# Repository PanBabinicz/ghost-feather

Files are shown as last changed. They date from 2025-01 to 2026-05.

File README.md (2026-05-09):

# Ghost Feather



> [!NOTE]
> **Please bear in mind that the workspace was primarily created for enjoyment
> and educational endeavors.**

> The MIT License (MIT)
>
> Copyright (c) 2011-2024 The Bootstrap Authors
>
> Permission is hereby granted, free of charge, to any person obtaining a copy
> of this software and associated documentation files (the "Software"), to deal
> in the Software without restriction, including without limitation the rights
> to use, copy, modify, merge, publish, distribute, sublicense, and/or sell
> copies of the Software, and to permit persons to whom the Software is
> furnished to do so, subject to the following conditions:
>
> The above copyright notice and this permission notice shall be included in
> all copies or substantial portions of the Software.
>
> THE SOFTWARE IS PROVIDED "AS IS", WITHOUT WARRANTY OF ANY KIND, EXPRESS OR
> IMPLIED, INCLUDING BUT NOT LIMITED TO THE WARRANTIES OF MERCHANTABILITY,
> FITNESS FOR A PARTICULAR PURPOSE AND NONINFRINGEMENT. IN NO EVENT SHALL THE
> AUTHORS OR COPYRIGHT HOLDERS BE LIABLE FOR ANY CLAIM, DAMAGES OR OTHER
> LIABILITY, WHETHER IN AN ACTION OF CONTRACT, TORT OR OTHERWISE, ARISING FROM,
> OUT OF OR IN CONNECTION WITH THE SOFTWARE OR THE USE OR OTHER DEALINGS IN
> THE SOFTWARE.

# Compilation process

> [!NOTE]
> **The current compilation process will be changed**

```console
~ arm-none-eabi-gcc -g -c -mfloat-abi=hard -mfpu=fpv4-sp-d16 -mcpu=cortex-m7 -mthumb \
                          -I memory -I bootloader \
                          startup/stm32f722xx/stm32722xx_startup.c -o build/stm32f722xx_startup.o
```

```console
~ arm-none-eabi-gcc -g -c -mfloat-abi=hard -mfpu=fpv4-sp-d16 -mcpu=cortex-m7 -mthumb \
                          -I libopencm3/include -I memory -DSTM32F7 \
                          bootloader/stm32f722xx_first_bootloader.c -o build/stm32f722xx_first_bootloader.o
```

```console
~ arm-none-eabi-as -g vectortable/stm32f722xx/stm32f722xx_vectortable.S -o build/stm32f722xx_vectortable.o
```

```console
~ arm-none-eabi-gcc -g -nostartfiles -nostdlib -mfloat-abi=hard -mfpu=fpv4-sp-d16 -mcpu=cortex-m7 -mthumb \
                       build/stm32f722xx_first_bootloader.o build/stm32f722xx_startup.o build/stm32f722xx_vectortable.o -o build/stm32f722xx_first_bootloader.elf \
                       -T linkerscript/stm32f722xx/stm32f722xx_bootloader.ld -L linkerscript/stm32f722xx -L libopencm3/lib -lopencm3_stm32f7
```

## CMake generators

> **Unix Makefiles**
>
> ```console
> ~ cmake -S . -B build -DCMAKE_TOOLCHAIN_FILE=arm-none-eabi-toolchain.cmake
> ~ cd build
> ~ cmake --build . --config Debug
> ```

> **Ninja Multi-Config**
>
> ```console
> ~ cmake -G "Ninja Multi-Config" -S . -B build -DCMAKE_TOOLCHAIN_FILE=arm-none-eabi-toolchain.cmake
> ~ cd build
> ~ cmake --build . --config Debug
> ```

> **CMake Presets**
>
> ```console
> ~ cmake --preset list
> ~ cmake --preset <build-type>
> ```

> **Build shell script**
>
> ```console
> ~ ./build.sh <build-type>
> ```

# How to program

> For now, CMake generates two elf files. Each of these files needs to be uploaded to the device.

# Newlib

> To use newlib with libopencm3 it is necessary to recomplie the libc to be able to use hard floating point numbers which use on-chip FPU.
> The second option is to use soft floating point numbers but the speed will be slower.

# Marco Paland printf implementation

> The Marco Paland printf implementation is a lightweight, standalone alternative designed
> specifically to address these limitations. This implementation offers a small memory footprint,
> portability, and independence from the full C standard library. It is widely used in embedded
> projects where developers require formatted output but cannot afford the code size and
> dependencies of a complete libc implementation.

# DFU script

> **Description**
>
> The script enables firmware update over USART. It allows users to upload binary firmware files to microcontroller-based devices with minimal effort.
> The script handles communication setup, data formatting, and transmission to ensure reliable updates.

> **Usage**
>
> ```console
> ~ python3 dfu_usart.py <binary> <port> <baudrate>
> ```
>
> - `<binary>`:   The firmware to be uploaded.
> - `<port>`:     The name of the serial port connected to the target device (e.g., /dev/tty.usbmodem).
> - `<baudrate>`: The communication speed in bits per second (e.g., 9600, 115200).

# SOCAT tool

> **Usage**
>
> ```console
> ~ socat -d -d PTY,raw,echo=0 PTY,raw,echo=0
> ~ stty -f /dev/ttysxxx 115200
> ~ screen /dev/ttysxxx 115200
> ```

# Unit tests

> **Description**
>
> The unit tests verify the functionality, reliability, and error handling of embedded system controllers using Google Test (GTest).
>
> They cover various scenarios, including:
> - Core functionality validation.
> - Boundary condition testing.
> - Error handling and fault tolerance.
> - Performance and efficiency checks.

> **Usage**
>
> ```console
> ~ cmake -G "Ninja" -S . -B build -DPROJECT_ROOT_DIR=$(pwd)/../..
> ~ cmake --build build
> ~ cd build && ctest
> ```

# Conda

## What is Conda?

> Conda is an open-source **package manager and environment manager** used for installing, running, and
> updating software packages and their dependencies. It is widely used in data science, machine learning,
> and scientific computing because it simplifies managing complex software environments.
>
> Unlike `pip`, which only installs Python packages, **Conda can manage packages written in multiple languages**
> (such as Python, R, and C libraries) and handles system-level dependencies as well.
>
> Conda is distributed with platforms such as:

- **Anaconda** – a large distribution that includes many preinstalled scientific packages.
- **Miniconda** – a lightweight version that installs only Conda and Python.

## Why Use Conda?

> Conda helps solve common development problems:

- **Dependency management** – automatically installs required libraries.
- **Environment isolation** – different projects can use different package versions.
- **Cross-language support** – works with Python, R, and other tools.
- **Reproducibility** – environments can be exported and recreated.

> Example: one project may require `Python 3.9` while another requires `Python 3.11`. Conda allows both to
> coexist without conflicts.

## Creating an Environment

> A Conda environment is an isolated workspace containing its own Python version and installed packages.
>
> Create a new environment:

```bash
conda create -n myenv python=3.10
```

Here:
- `-n myenv` specifies the environment name
- `python=3.10` installs a specific Python version

## Activating an Environment

> Before using an environment, it must be activated.

```bash
conda activate myenv
```

> After activation, all installed packages and Python commands will come from this environment.
>
> To deactivate:

```bash
conda deactivate
```

## Installing Packages

> Packages can be installed directly into the active environment.

```bash
conda install numpy pandas matplotlib
```

> Conda will automatically resolve and install required dependencies.

## Listing Environments

> To see all available environments:

```bash
conda env list
```

> or:

```bash
conda info --envs
```

## Removing an Environment

> If an environment is no longer needed, it can be deleted:

```bash
conda remove -n myenv --all
```

## Exporting an Environment

> To share or reproduce an environment:

```bash
conda env export > environment.yml
```

> This file can later be used to recreate the same environment.

## Recreating an Environment

```bash
conda env create -f environment.yml
```

> This installs all packages and dependencies exactly as defined in the exported file.

## EASTER EGG!

> CBR 929 broke. We have to repair it. I will do todays job tomorrow.

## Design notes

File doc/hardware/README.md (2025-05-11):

# Hardware

## Important links

> Phil's lab
>
> Bluetooth Hardware Design  
> https://www.youtube.com/watch?v=nkHFoxe0mrU&ab_channel=Phil%E2%80%99sLab  
> https://www.youtube.com/watch?v=PlXd3lLZ4vc&t=16s&ab_channel=Phil%E2%80%99sLab

> Over-the-Air DFU procedure
>
> https://onlinedocs.microchip.com/oxy/GUID-26457D23-798C-47B0-9F40-C5DA6E995C6F-en-US-2/GUID-79B3231C-7BD0-4459-80A5-A198A4F1B366.html

## 🖥 PCB Design Software

> KiCad
>
> KiCad is a free and open-source software suite for designing schematics and PCB layouts.
> It is widely used in the electronics community for both hobbyist and professional projects.

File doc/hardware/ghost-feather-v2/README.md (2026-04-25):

# 👻 Ghost Feather v2

## Introduction

> [!NOTE]  
> **Please bear in mind that the pcb was primarily created for enjoyment  
> and educational endeavors.**

> Ghost Feather v2 is a compact, four-layer PCB built for embedded systems and robotics exploration 🤖.
> This revision evolves the original design into a more capable flight-control-oriented platform,
> integrating additional sensors and support for modern FPV and radio systems.
>
> ✨ This version expands beyond basic functionality, introducing orientation awareness, altitude sensing,
> and improved control reliability.

## ✨ Key Features

- 🧠 STM32F722RET6 – Powerful Cortex-M7 MCU at the heart of the board

- 🌀 BMI088 IMU – High-performance 6-axis sensor optimized for vibration-heavy environments

- 🧭 IIS2MDCTR Magnetometer – 3-axis magnetic field sensing for heading and navigation

- 🌡️ BMP390 Barometer – High-resolution pressure sensor for altitude estimation

- 📡 External ELRS Receiver Support – Designed for use with Radiomaster RP3 (ExpressLRS 2.4 GHz) via CRSF protocol

- 🧪 Voltage Level Shifters – Built using MOSFETs to safely bridge logic levels

- 🛠️ SWD Tag Connector – For easy debugging and programming

- 🔌 4x PicoBlade Connectors – For connecting ESCs (Electronic Speed Controllers)

- 📡 1x PicoBlade Connector – Reserved for RF receiver (UART: CRSF)

- 🎥 FPV Camera Support – Dedicated power and video signal connections for analog FPV systems

## 🔧 Design Notes

- The board is designed to work with external ExpressLRS receivers, such as the Radiomaster RP3, avoiding the
  complexity of onboard RF design.

- Sensor suite upgrades (IMU, magnetometer, barometer) allow for advanced flight control and navigation
  capabilities.

- FPV support is implemented at the hardware level (power + signal routing), without onboard video processing.

## 🚧 Future Improvements

- Blackbox logging (SPI flash)
- OSD support (e.g., AT7456E)
- USB-C interface
- Improved power filtering for analog systems

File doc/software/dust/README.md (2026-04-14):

# DUST protocol

## Description

> The DUST communication protocol is a lightweight and reliable data transfer mechanism designed for
> Device Firmware Update (DFU) operations in ghost feather system. It supports flexible payload sizes, allowing
> efficient transmission of firmware data across varying link conditions. Data integrity is ensured through
> integrated CRC and checksum validation, minimizing the risk of corrupted updates. The protocol includes
> acknowledgment and retransmission mechanisms to guarantee delivery and robustness in unstable or lossy communication
> environments.

## Protocol structures

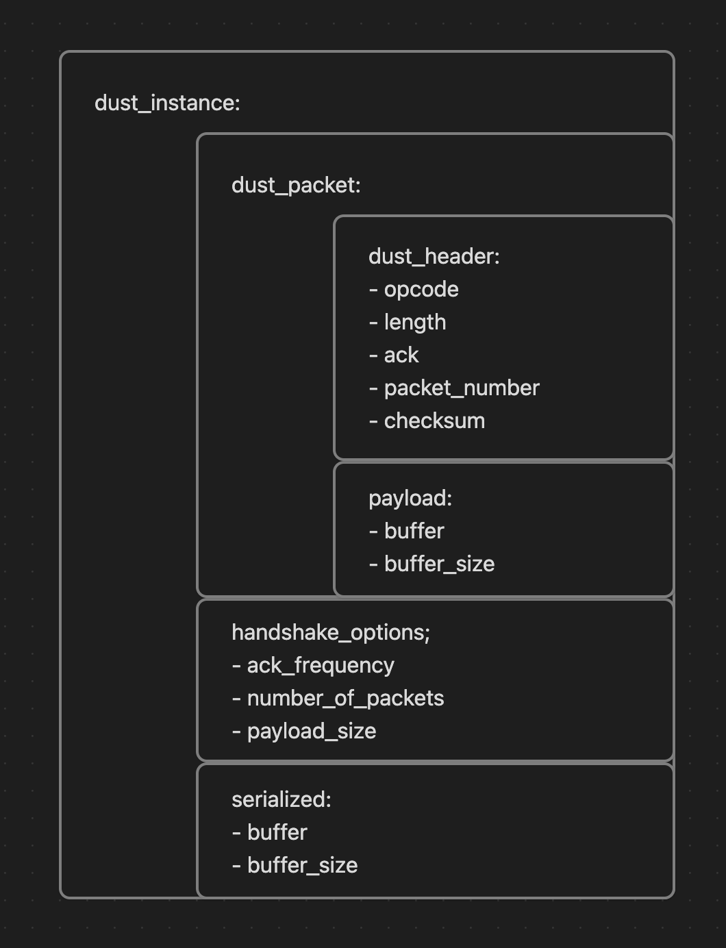
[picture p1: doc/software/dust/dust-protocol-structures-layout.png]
dust-protocol-structures-layout


## Packet structure

> <table class="tg"><thead>
>   <tr>
>     <td class="tg-uzvj" rowspan="12">DUST<br>PACKET</td>
>     <td class="tg-uzvj" rowspan="5">HEADER<br>(4bytes)</td>
>     <td class="tg-7btt">OPCODE<br>(2bits)</td>
>   </tr>
>   <tr>
>     <td class="tg-7btt">LENGTH<br>(2bits)</td>
>   </tr>
>   <tr>
>     <td class="tg-7btt">ACK FLAG<br>(1bit)</td>
>   </tr>
>   <tr>
>     <td class="tg-7btt">PACKET NUMBER<br>(11bits)</td>
>   </tr>
>   <tr>
>     <td class="tg-7btt">CHECKSUM<br>(16bits)</td>
>   </tr>
>   <tr>
>     <td class="tg-uzvj" rowspan="6">PAYLOAD<br>(32-256bytes)</td>
>     <td class="tg-uzvj">DATA[0]</td>
>   </tr>
>   <tr>
>     <td class="tg-uzvj">DATA[1]</td>
>   </tr>
>   <tr>
>     <td class="tg-uzvj">DATA[3]</td>
>   </tr>
>   <tr>
>     <td class="tg-uzvj">...</td>
>   </tr>
>   <tr>
>     <td class="tg-uzvj">DATA[n-1]</td>
>   </tr>
>   <tr>
>     <td class="tg-uzvj">DATA[n]</td>
>   </tr>
>   <tr>
>     <td class="tg-uzvj">CRC16<br>(2bytes)</td>
>     <td class="tg-uzvj">CRC16<br></td>
>   </tr></thead></table>

### OPCODE (2 bits wide)

> | OPCODE     | VALUE |
> |------------|-------|
> | CONNECT    | 0x00  |
> | DISCONNECT | 0x01  |
> | DATA       | 0x02  |
> | ERROR      | 0x03  |
>
> ### LENGTH (2 bits wide)
>
> | LENGTH     | VALUE |
> |------------|-------|
> | BYTE32     | 0x00  |
> | BYTE64     | 0x01  |
> | BYTE128    | 0x02  |
> | BYTE256    | 0x03  |
>
> ### ACK (1 bits wide)
>
> | LENGTH     | VALUE |
> |------------|-------|
> | UNSET      | 0x00  |
> | SET        | 0x01  |

### PACKET NUMBER (11 bits wide)

> The packet number is used to enumerate the packets. When error occurs the transmitter is signaled which
> packet was corrupted with the help of this filed.

### CHECKSUM (16 bits wide)

> The checksum purpose is error detection that may have been introduced during header transmission.
>
> Algorithm used to calculate the checksum:
>
> ``` code
> checksum = ((opcode << 0x0e) | (length << 0x0c) | (ack << 0x0b) | (packet_number << 0x00));
> checksum = ~checksum;
> ```

### HANDSHAKE OPTIONS

> Handshake options are send in payload when a connection attempt is made.
> The first byte stores information about ACK packet frequency (rate), the next four bytes have information about number of packets.

## Connection establishment (handshake)

> The connection establishment sets the payload size for future data packets. In this process only header is sent.
> The receiver calculates the checksum of the header and check it's correctness. It then sends an ACK header.

```mermaid
sequenceDiagram
    UPDATER->>DEVICE: CONNECT PACKET
    DEVICE-->>UPDATER: CONNECT ACK PACKET
```

### CONNECT PACKET

> <table class="tg"><thead>
>   <tr>
>     <td class="tg-uzvj" rowspan="12">DUST<br>PACKET</td>
>     <td class="tg-uzvj" rowspan="5">HEADER<br>(4bytes)</td>
>     <td class="tg-7btt">0x00<br>(2bits)</td>
>   </tr>
>   <tr>
>     <td class="tg-7btt">0x00<br>(2bits)</td>
>   </tr>
>   <tr>
>     <td class="tg-7btt">0x00<br>(1bit)</td>
>   </tr>
>   <tr>
>     <td class="tg-7btt">0x00<br>(11bits)</td>
>   </tr>
>   <tr>
>     <td class="tg-7btt">0xffff<br>(16bits)</td>
>   </tr>
>   <tr>
>     <td class="tg-uzvj" rowspan="6">PAYLOAD<br>(32-256bytes)</td>
>     <td class="tg-uzvj">0x00</td>
>   </tr>
>   <tr>
>     <td class="tg-uzvj">0x00</td>
>   </tr>
>   <tr>
>     <td class="tg-uzvj">0x00</td>
>   </tr>
>   <tr>
>     <td class="tg-uzvj">...</td>
>   </tr>
>   <tr>
>     <td class="tg-uzvj">0x00</td>
>   </tr>
>   <tr>
>     <td class="tg-uzvj">0x00</td>
>   </tr>
>   <tr>
>     <td class="tg-uzvj">CRC16<br>(2bytes)</td>
>     <td class="tg-uzvj">0xa9b8<br></td>
>   </tr></thead>
> </table>

### CONNECT ACK PACKET

> <table class="tg"><thead>
>   <tr>
>     <td class="tg-uzvj" rowspan="12">DUST<br>PACKET</td>
>     <td class="tg-uzvj" rowspan="5">HEADER<br>(4bytes)</td>
>     <td class="tg-7btt">0x00<br>(2bits)</td>
>   </tr>
>   <tr>
>     <td class="tg-7btt">0x00<br>(2bits)</td>
>   </tr>
>   <tr>
>     <td class="tg-7btt">0x01<br>(1bit)</td>
>   </tr>
>   <tr>
>     <td class="tg-7btt">0x00<br>(11bits)</td>
>   </tr>
>   <tr>
>     <td class="tg-7btt">0xffff<br>(16bits)</td>
>   </tr>
>   <tr>
>     <td class="tg-uzvj" rowspan="6">PAYLOAD<br>(32-256bytes)</td>
>     <td class="tg-uzvj">0x00</td>
>   </tr>
>   <tr>
>     <td class="tg-uzvj">0x00</td>
>   </tr>
>   <tr>
>     <td class="tg-uzvj">0x00</td>
>   </tr>
>   <tr>
>     <td class="tg-uzvj">...</td>
>   </tr>
>   <tr>
>     <td class="tg-uzvj">0x00</td>
>   </tr>
>   <tr>
>     <td class="tg-uzvj">0x00</td>
>   </tr>
>   <tr>
>     <td class="tg-uzvj">CRC16<br>(2bytes)</td>
>     <td class="tg-uzvj">0x3508<br></td>
>   </tr></thead>
> </table>

## Data transmission

> During data transmission, firmware bytes are sent in the payload.
> The rate of ACK packets depends on the options passed during the handshake.

 ```mermaid
 sequenceDiagram
     UPDATER->>DEVICE: DATA[0] PACKET
     UPDATER->>DEVICE: DATA[1] PACKET
     UPDATER->>DEVICE: DATA[2] PACKET
     UPDATER->>DEVICE: ...
     UPDATER->>DEVICE: DATA[n] PACKET
     DEVICE-->>UPDATER: DATA ACK PACKET
     UPDATER->>DEVICE: DATA[n+1] PACKET
     UPDATER->>DEVICE: ...
 ```

## Disconnection

> Disconnection is performed from slave side. The device that updates itself
> sends the disconnection packet after the last data is received.

 ```mermaid
 sequenceDiagram
     DEVICE-->>UPDATER: DISCONNECTION PACKET
     UPDATER->>DEVICE: DISCONNECTION PACKET ACK
 ```

### DISCONNECTION PACKET

> <table class="tg"><thead>
>   <tr>
>     <td class="tg-uzvj" rowspan="12">DUST<br>PACKET</td>
>     <td class="tg-uzvj" rowspan="5">HEADER<br>(4bytes)</td>
>     <td class="tg-c3ow">0x01</td>
>   </tr>
>   <tr>
>     <td class="tg-c3ow">0x00</td>
>   </tr>
>   <tr>
>     <td class="tg-c3ow">0x00</td>
>   </tr>
>   <tr>
>     <td class="tg-9wq8">0x00</td>
>   </tr>
>   <tr>
>     <td class="tg-c3ow">0xbfff</td>
>   </tr>
>   <tr>
>     <td class="tg-uzvj" rowspan="6">PAYLOAD<br>(32-256bytes)</td>
>     <td class="tg-9wq8">0x00</td>
>   </tr>
>   <tr>
>     <td class="tg-9wq8">0x00</td>
>   </tr>
>   <tr>
>     <td class="tg-9wq8"><span style="font-style:normal">0x00</span></td>
>   </tr>
>   <tr>
>     <td class="tg-9wq8">...</td>
>   </tr>
>   <tr>
>     <td class="tg-9wq8"><span style="font-style:normal">0x00</span></td>
>   </tr>
>   <tr>
>     <td class="tg-9wq8"><span style="font-style:normal">0x00</span></td>
>   </tr>
>   <tr>
>     <td class="tg-uzvj">CRC16<br>(2bytes)</td>
>     <td class="tg-9wq8">0x0577</td>
>   </tr></thead>
> </table>

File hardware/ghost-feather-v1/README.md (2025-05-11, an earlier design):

# Ghost Feather - hardware

## PCB used materials

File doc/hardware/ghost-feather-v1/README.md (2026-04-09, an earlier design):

# 👻 Ghost Feather v1

## Introduction

> [!NOTE]
> **Please bear in mind that the pcb was primarily created for enjoyment
> and educational endeavors.**

> Ghost Feather v1 is a compact, four-layer PCB built for embedded systems and robotics exploration 🤖.
> Designed with versatility and performance in mind, it brings together a robust set of components for
> a wide range of applications.
>
> This is the first version of the board, featuring only basic functionality – telemetry and advanced
> features are not yet included.

> ✨ Key Features
>
> - 🧠 STM32F722RET6 – Powerful Cortex-M7 MCU at the heart of the board
>
> - 🌀 BMI270 IMU – 6-axis motion sensing for orientation and motion tracking
>
> - 🧪 Voltage Level Shifters – Built using MOSFETs to safely bridge logic levels
>
> - 🛠️ SWD Tag Connector – For easy debugging and programming
>
> - 🔌 4x PicoBlade Connectors – For connecting ESCs (Electronic Speed Controllers)
>
> - 📡 1x PicoBlade Connector – For connecting an RF radio module

## 📃 Schematic

> This section includes the complete schematic of the board, created with KiCad.
> It outlines the core circuitry, microcontroller wiring, level shifters, connectors, and power.

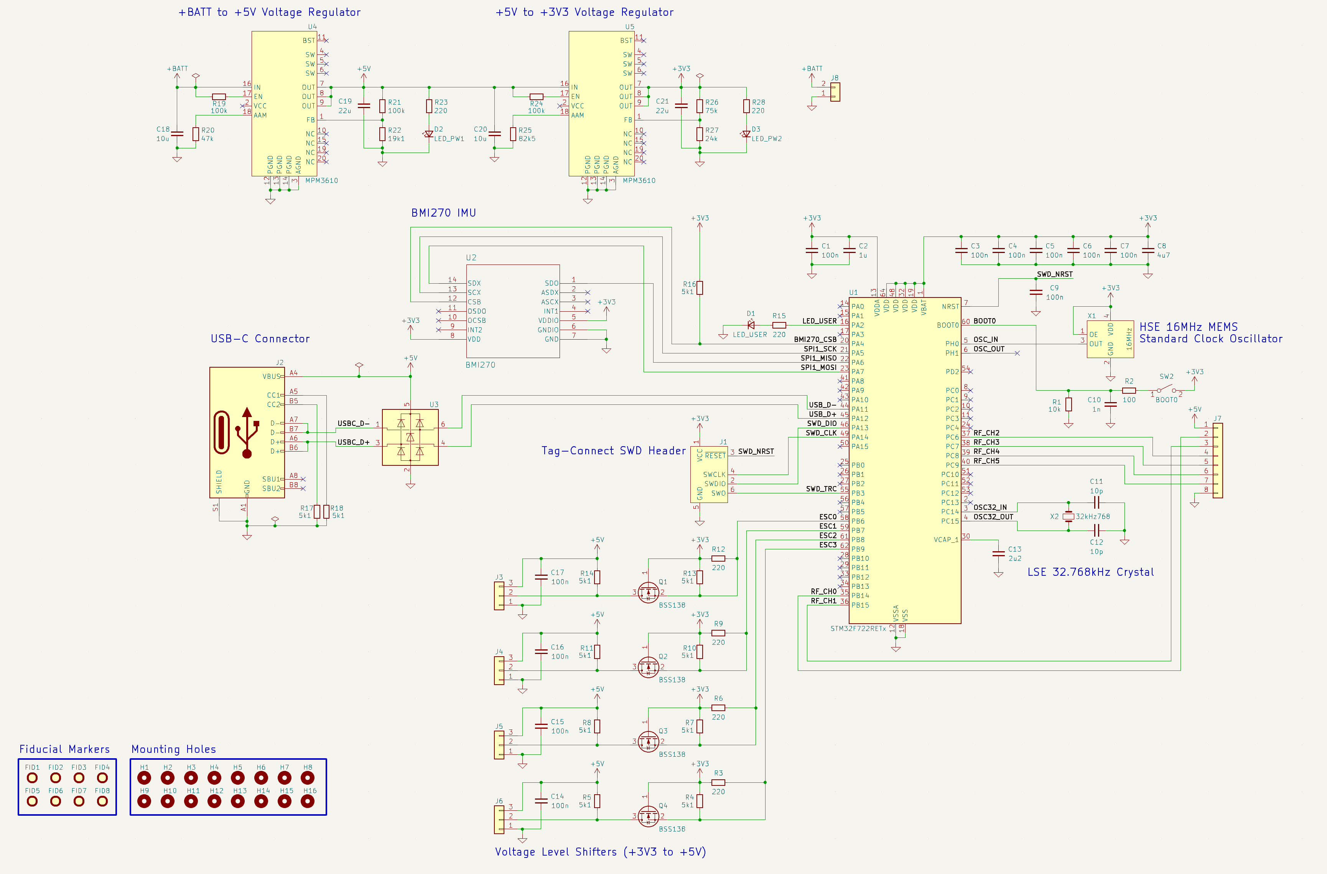
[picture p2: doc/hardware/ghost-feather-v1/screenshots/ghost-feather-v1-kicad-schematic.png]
Schematic


## 🛠️ PCB

> This section showcases the 3D views of the PCB, generated using KiCad.
> These models provide a clear visual reference for component placement,
> board layout, and connector orientation.

### KiCAD 3D Model
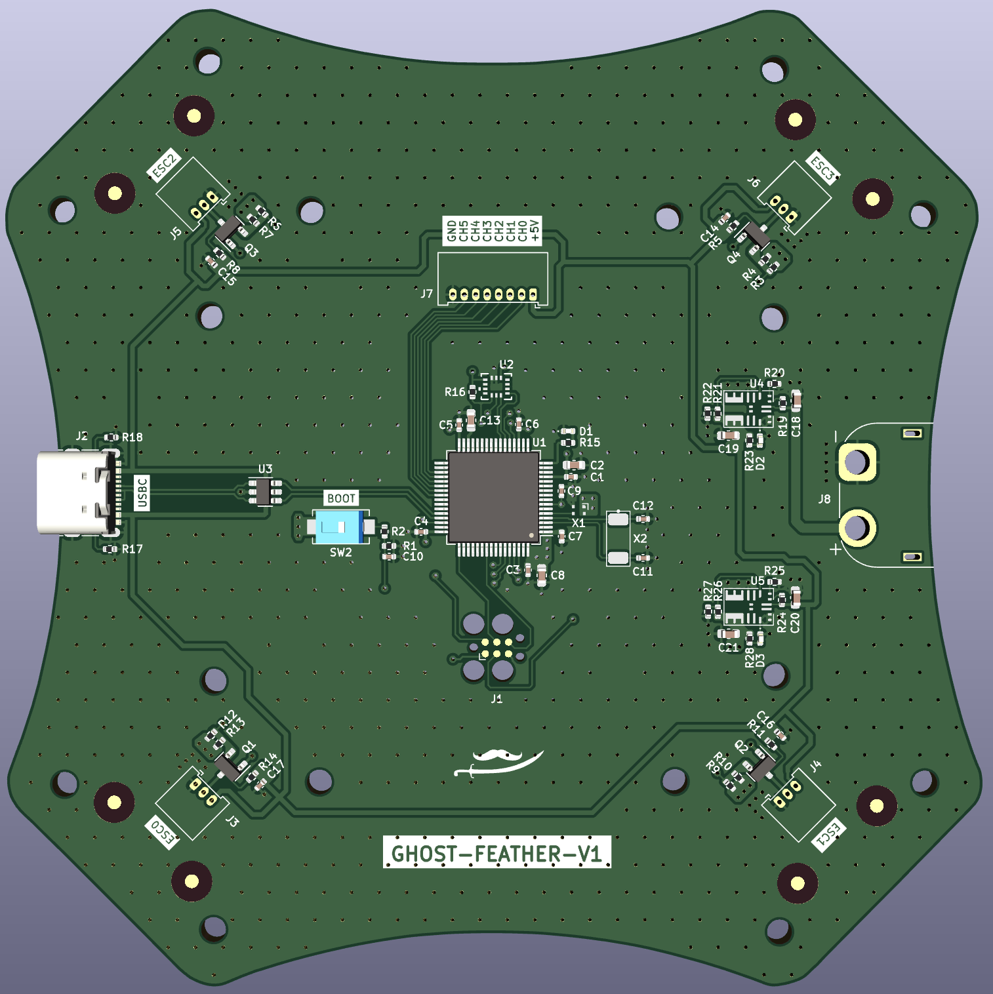
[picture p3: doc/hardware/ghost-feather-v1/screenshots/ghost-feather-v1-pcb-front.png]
Front

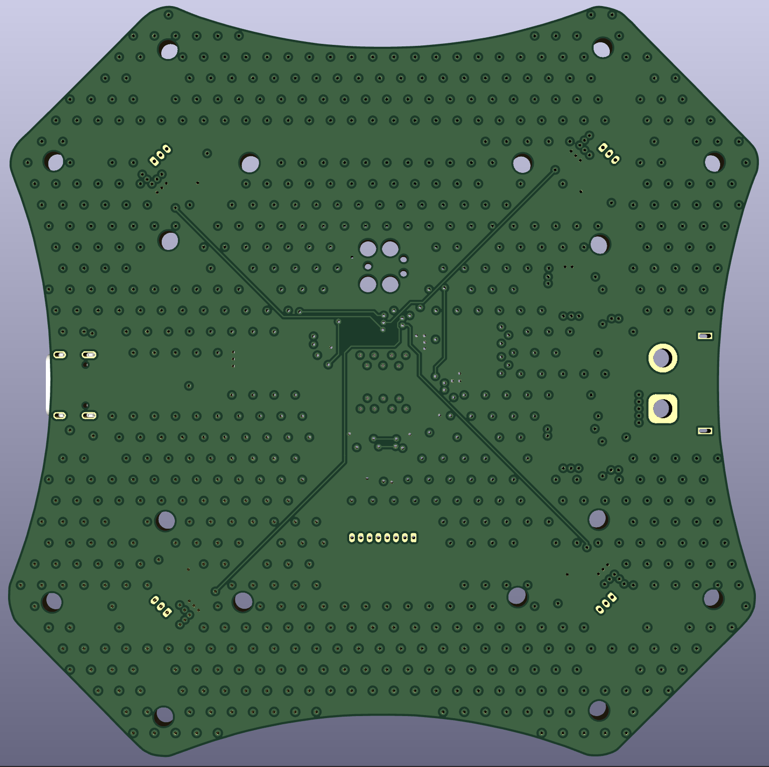
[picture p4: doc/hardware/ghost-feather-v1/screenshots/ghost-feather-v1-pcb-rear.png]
Rear


### Manufactured PCB
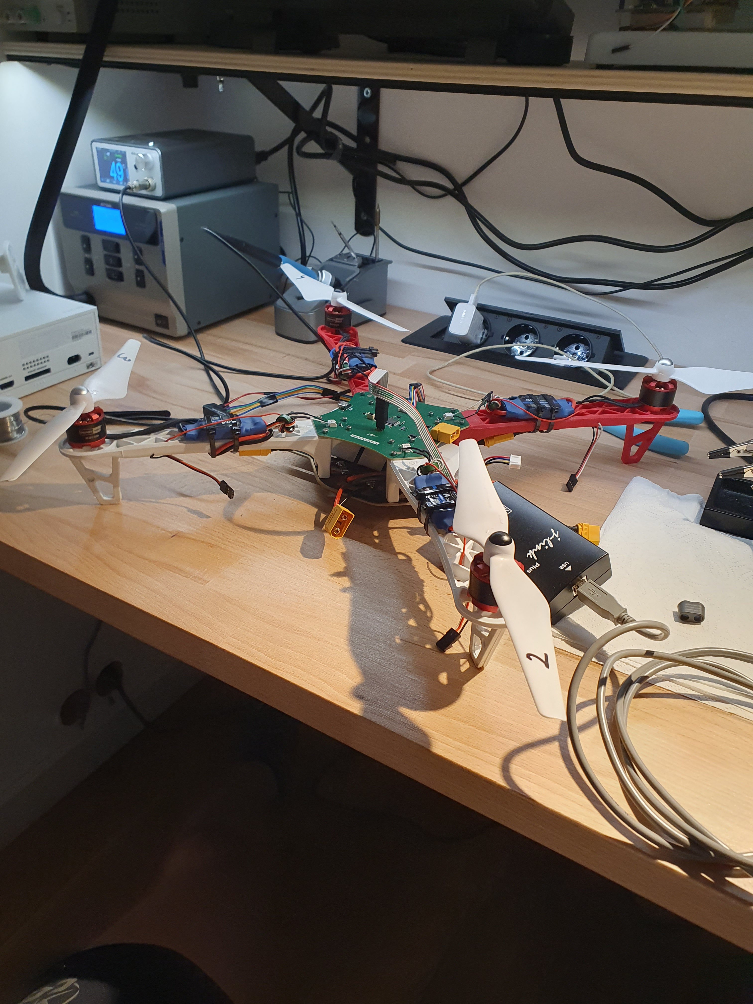
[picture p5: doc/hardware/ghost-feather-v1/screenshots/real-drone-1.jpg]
Bench

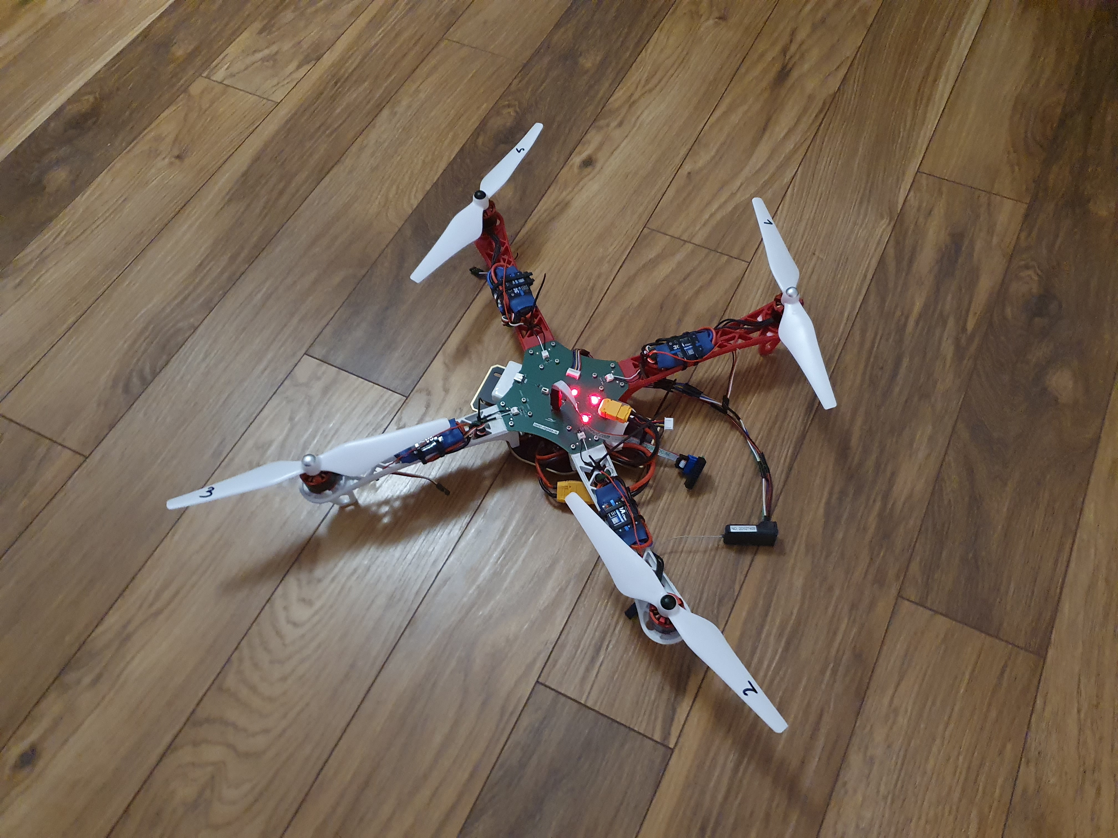
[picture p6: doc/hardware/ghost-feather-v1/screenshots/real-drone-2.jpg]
Floor


## PID Gain Tuning Using a Dedicated Test Stand

### Preparation for tuning PID gains
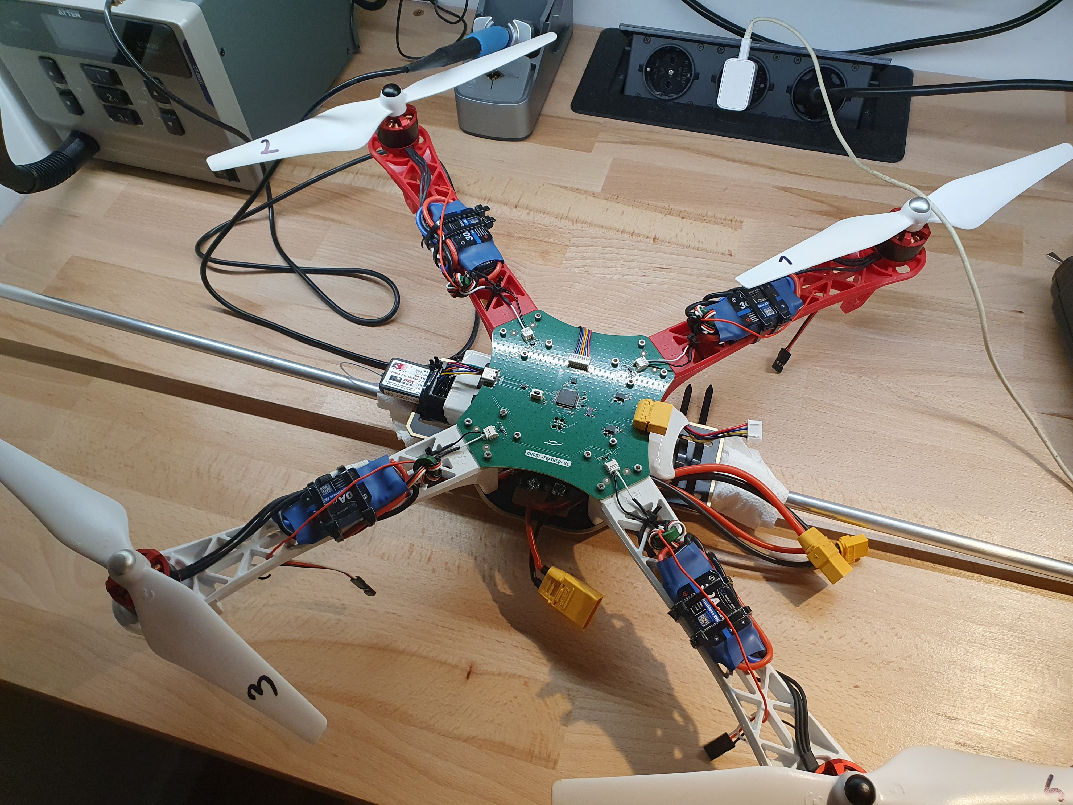
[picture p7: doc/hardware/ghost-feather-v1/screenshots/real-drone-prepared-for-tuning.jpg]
OnBench


> To obtain accurate and repeatable PID gains for the drone, a **dedicated tuning stand** is used. This setup allows controlled
> testing of the control system without the risks and external disturbances associated with free flight.

### 🧩 Purpose

> The tuning stand isolates the drone’s rotational axes (typically roll and pitch) while:
> * preventing full movement or lift-off
> * allowing safe application of control inputs
>
> This creates a controlled environment for systematic PID tuning.

### ⚙️ Setup

> The drone is mounted on a mechanical frame that:
> * constrains motion to one axis at a time
> * minimizes friction and external disturbances
> * allows sensors (e.g., IMU) to operate normally
>
> Only the axis under test (e.g., roll) is left free to rotate, while others are fixed.

### 🔄 Tuning Procedure

#### 1. Proportional Gain (Kp)
> * Start with `Ki = 0`, `Kd = 0`
> * Gradually increase `Kp` until the system responds quickly to disturbances
> * Identify the point where oscillations begin, then slightly reduce `Kp`

#### 2. Derivative Gain (Kd)
> * Increase `Kd` to dampen oscillations
> * Adjust until the system stabilizes quickly without overshoot

#### 3. Integral Gain (Ki)
> * Introduce `Ki` to eliminate steady-state error
> * Increase slowly to avoid drift or slow oscillations

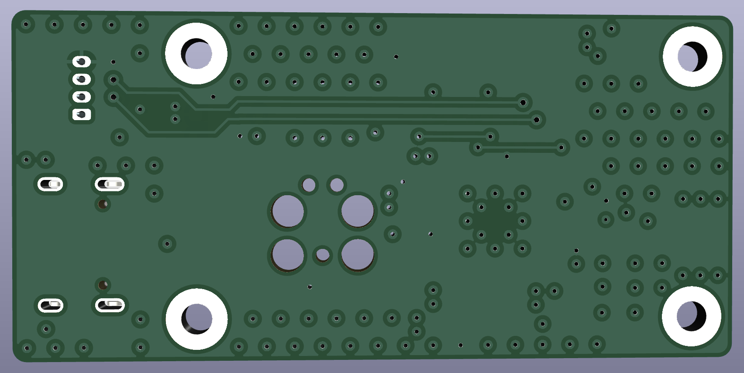
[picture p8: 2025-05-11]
hardware/flying-byte-v1/screenshots/rear.png

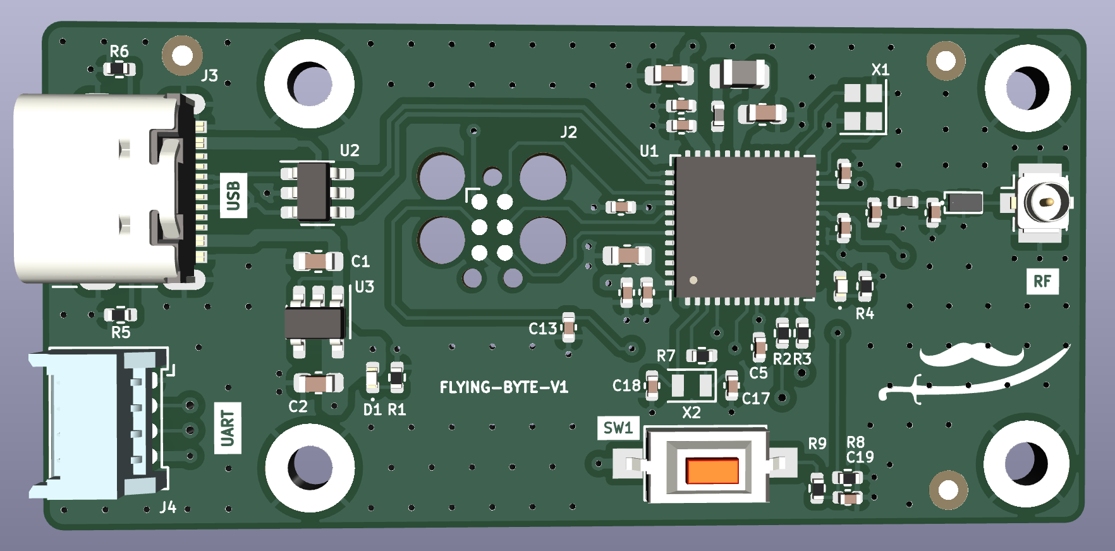
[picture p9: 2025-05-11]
hardware/flying-byte-v1/screenshots/front.png

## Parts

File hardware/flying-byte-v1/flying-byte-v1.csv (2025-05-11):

Reference | Value | Footprint | Datasheet | Distribution Link | Manufacturer Part Number | Manufaturer | Qty
C1-C3, C10, C14 | 4u7 | Capacitor_SMD:C_0603_1608Metric | ~ | https://eu.mouser.com/ProductDetail/Murata-Electronics/GRT188R61E475KE13D | GRT188R61E475KE13D | Murata Electronics | 5
C4-C9, C11-C13, C19 | 100n | Capacitor_SMD:C_0402_1005Metric | ~ | https://eu.mouser.com/ProductDetail/Wurth-Elektronik/885012205092 | 885012205092 | Wurth Elektronik | 10
C15 | 0p8 | Capacitor_SMD:C_0402_1005Metric | ~ | https://eu.mouser.com/ProductDetail/Murata-Electronics/GRM1555C1HR80BA01D?qs=e%252BE4OD6MgMezPYPintwvrA%3D%3D | GRM1555C1HR80BA01D | Murata Electronics | 1
C16 | 0p3 | Capacitor_SMD:C_0402_1005Metric | ~ | https://eu.mouser.com/ProductDetail/Murata-Electronics/GRM1555C1HR30WA01D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 | GRM1555C1HR30WA01D | Murata Electronics | 1
C17, C18 | 10p | Capacitor_SMD:C_0402_1005Metric | ~ | https://eu.mouser.com/ProductDetail/KEMET/C0402C100J5RAC?qs=9vOqFld9vZUpzu%252Bf5E%252Bmyw%3D%3D | C0402C100J5RAC | KEMET | 2
D1, D2 | LED | LED_SMD:LED_0402_1005Metric | ~ | -- mixed values -- | -- mixed values -- | Stanley Electric | 2
FLT1 | DLF162500LT-5028A1 | flying-byte-v1-pcb-footprints:DLF162500LT-5028A1 | https://product.tdk.com/system/files/dam/doc/product/rf/rf/filter/catalog/rf_lpf_dlf162500lt-5028a1_en.pdf | https://eu.mouser.com/ProductDetail/TDK/DLF162500LT-5028A1?qs=U%2FZX79kHR%2FlwIbAISCs3qA%3D%3D | DLF162500LT-5028A1 | TDK | 1
J1 | Conn_Coaxial | Connector_Coaxial:U.FL_Hirose_U.FL-R-SMT-1_Vertical | ~ | https://eu.mouser.com/ProductDetail/Hirose-Connector/U.FL-R-SMT01?qs=Ux3WWAnHpjDV3tCCbDi65g%3D%3D | U.FL-R-SMT(01) | Hirose Connector | 1
J2 | Conn_ARM_SWD_TagConnect_TC2030 | Connector:Tag-Connect_TC2030-IDC-FP_2x03_P1.27mm_Vertical | https://www.tag-connect.com/wp-content/uploads/bsk-pdf-manager/TC2030-CTX_1.pdf |  |  |  | 1
J3 | USB_C_Receptacle_USB2.0 | Connector_USB:USB_C_Receptacle_GCT_USB4105-xx-A_16P_TopMnt_Horizontal | https://www.usb.org/sites/default/files/documents/usb_type-c.zip | https://eu.mouser.com/ProductDetail/GCT/USB4105-GF-A?qs=KUoIvG%2F9IlY%2FMLlBMpStpA%3D%3D | USB4105-GF-A | GCT | 1
J4 | Conn_01x04 | Connector_Molex:Molex_PicoBlade_53047-0410_1x04_P1.25mm_Vertical | ~ | https://eu.mouser.com/ProductDetail/Molex/53048-0410?qs=359VwiUTsp2msj5Tobchuw%3D%3D | 53048-0410 | Molex | 1
L1 | 10n | Inductor_SMD:L_0402_1005Metric | ~ | https://eu.mouser.com/ProductDetail/Murata-Electronics/LQG15WZ10NJ02D?qs=60uY6ySkanT1eJ7IaeAl%2Fg%3D%3D | LQG15WZ10NJ02D | Murata Electronics | 1
L2 | 10u | Inductor_SMD:L_0805_2012Metric | ~ | https://eu.mouser.com/ProductDetail/Murata-Electronics/LQM21FN100M80L?qs=%2F%252BYoplLUB5jHVlRNWlo0OQ%3D%3D | LQM21FN100M80L | Murata Electronics | 1
L3 | 2n7 | Inductor_SMD:L_0402_1005Metric | ~ | https://eu.mouser.com/ProductDetail/Murata-Electronics/LQG15HS2N7S02D?qs=ctz47l0uL1AKrLI74yO5Qw%3D%3D | LQG15HS2N7S02D | Murata Electronics | 1
R1-R4, R9 | 220R | Resistor_SMD:R_0402_1005Metric | ~ | https://eu.mouser.com/ProductDetail/SEI-Stackpole/RNCF0402BKE220R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 | RNCF0402BKE220R | SEI Stackpole | 5
R5, R6, R8 | 5k1 | Resistor_SMD:R_0402_1005Metric | ~ | https://eu.mouser.com/ProductDetail/SEI-Stackpole/RNCF0402BKE5K10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 | RNCF0402BKE5K10 | SEI Stackpole | 3
R7 | 0 | Resistor_SMD:R_0402_1005Metric | ~ | https://eu.mouser.com/ProductDetail/Vishay-Beyschlag/MCS04020Z0000ZE000?qs=1PkaV7r7jRAw43UYAxSbQw%3D%3D | MCS04020Z0000ZE000 | Vishay / Beyschlag | 1
SW1 | SW_Push | Button_Switch_SMD:SW_SPST_CK_RS282G05A3 | ~ | https://eu.mouser.com/ProductDetail/CK/RS282G05A3SMRT?qs=Gufeu08L%2Fl2VU43xmeLp5Q%3D%3D | RS282G05A3SMRT | C&K | 1
U1 | STM32WB55CEU6 | Package_DFN_QFN:QFN-48-1EP_7x7mm_P0.5mm_EP5.6x5.6mm | https://www.st.com/resource/en/datasheet/stm32wb55ce.pdf | https://eu.mouser.com/ProductDetail/STMicroelectronics/STM32WB55CEU6?qs=l7cgNqFNU1h38DnIgipayw%3D%3D | STM32WB55CEU6 | STMicroelectronics | 1
U2 | USBLC6-2SC6_MOD | Package_TO_SOT_SMD:SOT-23-6 | https://www.st.com/resource/en/datasheet/usblc6-2.pdf | https://eu.mouser.com/ProductDetail/STMicroelectronics/USBLC6-2SC6?qs=po45yt2pPpu%2FhNIlwQdTlg%3D%3D | USBLC6-2SC6 | STMicroelectronics | 1
U3 | MIC5365-3.3YD5 | Package_TO_SOT_SMD:SOT-23-5 | http://ww1.microchip.com/downloads/en/DeviceDoc/mic5365.pdf | https://eu.mouser.com/ProductDetail/Microchip-Technology/MIC5365-3.3YD5-TR?qs=U6T8BxXiZAXzRinbbfZRrg%3D%3D | MIC5365-3.3YD5-TR | Microchip Technology | 1
X1 | 32MHz | Crystal:Crystal_SMD_2016-4Pin_2.0x1.6mm | ~ | https://eu.mouser.com/ProductDetail/NDK/NX2016SA-32M-EXS00A-CS06465?qs=w%2Fv1CP2dgqr82b0JjRnv4A%3D%3D | NX2016SA-32M-EXS00A-CS06465 | NDK | 1
X2 | 32kHz768 | Crystal:Crystal_SMD_2012-2Pin_2.0x1.2mm | ~ | https://eu.mouser.com/ProductDetail/NDK/NX2012SA-32.768K-STD-MUB-1?qs=55YtniHzbhA%252B6%2Fl1MwFZaQ%3D%3D | NX2012SA-32.768K-STD-MUB-1 | NDK | 1

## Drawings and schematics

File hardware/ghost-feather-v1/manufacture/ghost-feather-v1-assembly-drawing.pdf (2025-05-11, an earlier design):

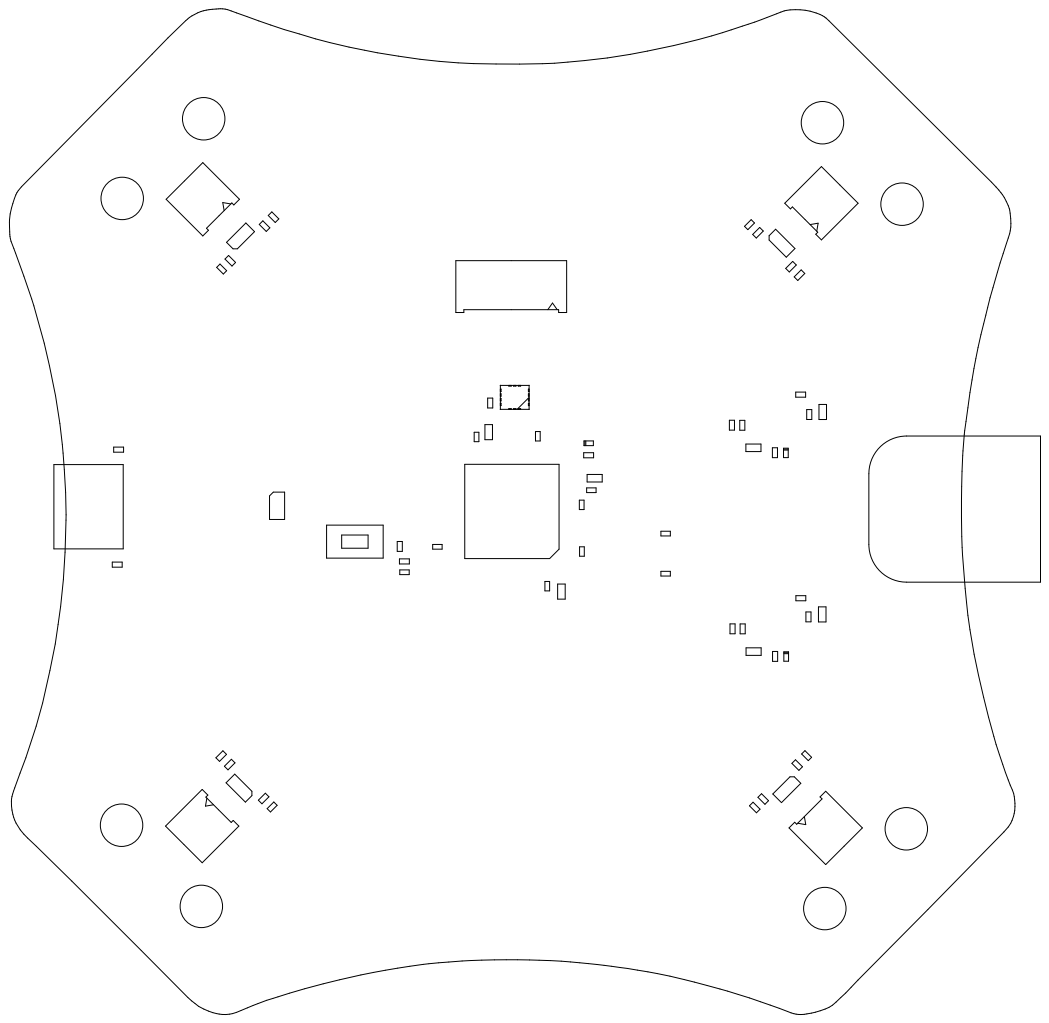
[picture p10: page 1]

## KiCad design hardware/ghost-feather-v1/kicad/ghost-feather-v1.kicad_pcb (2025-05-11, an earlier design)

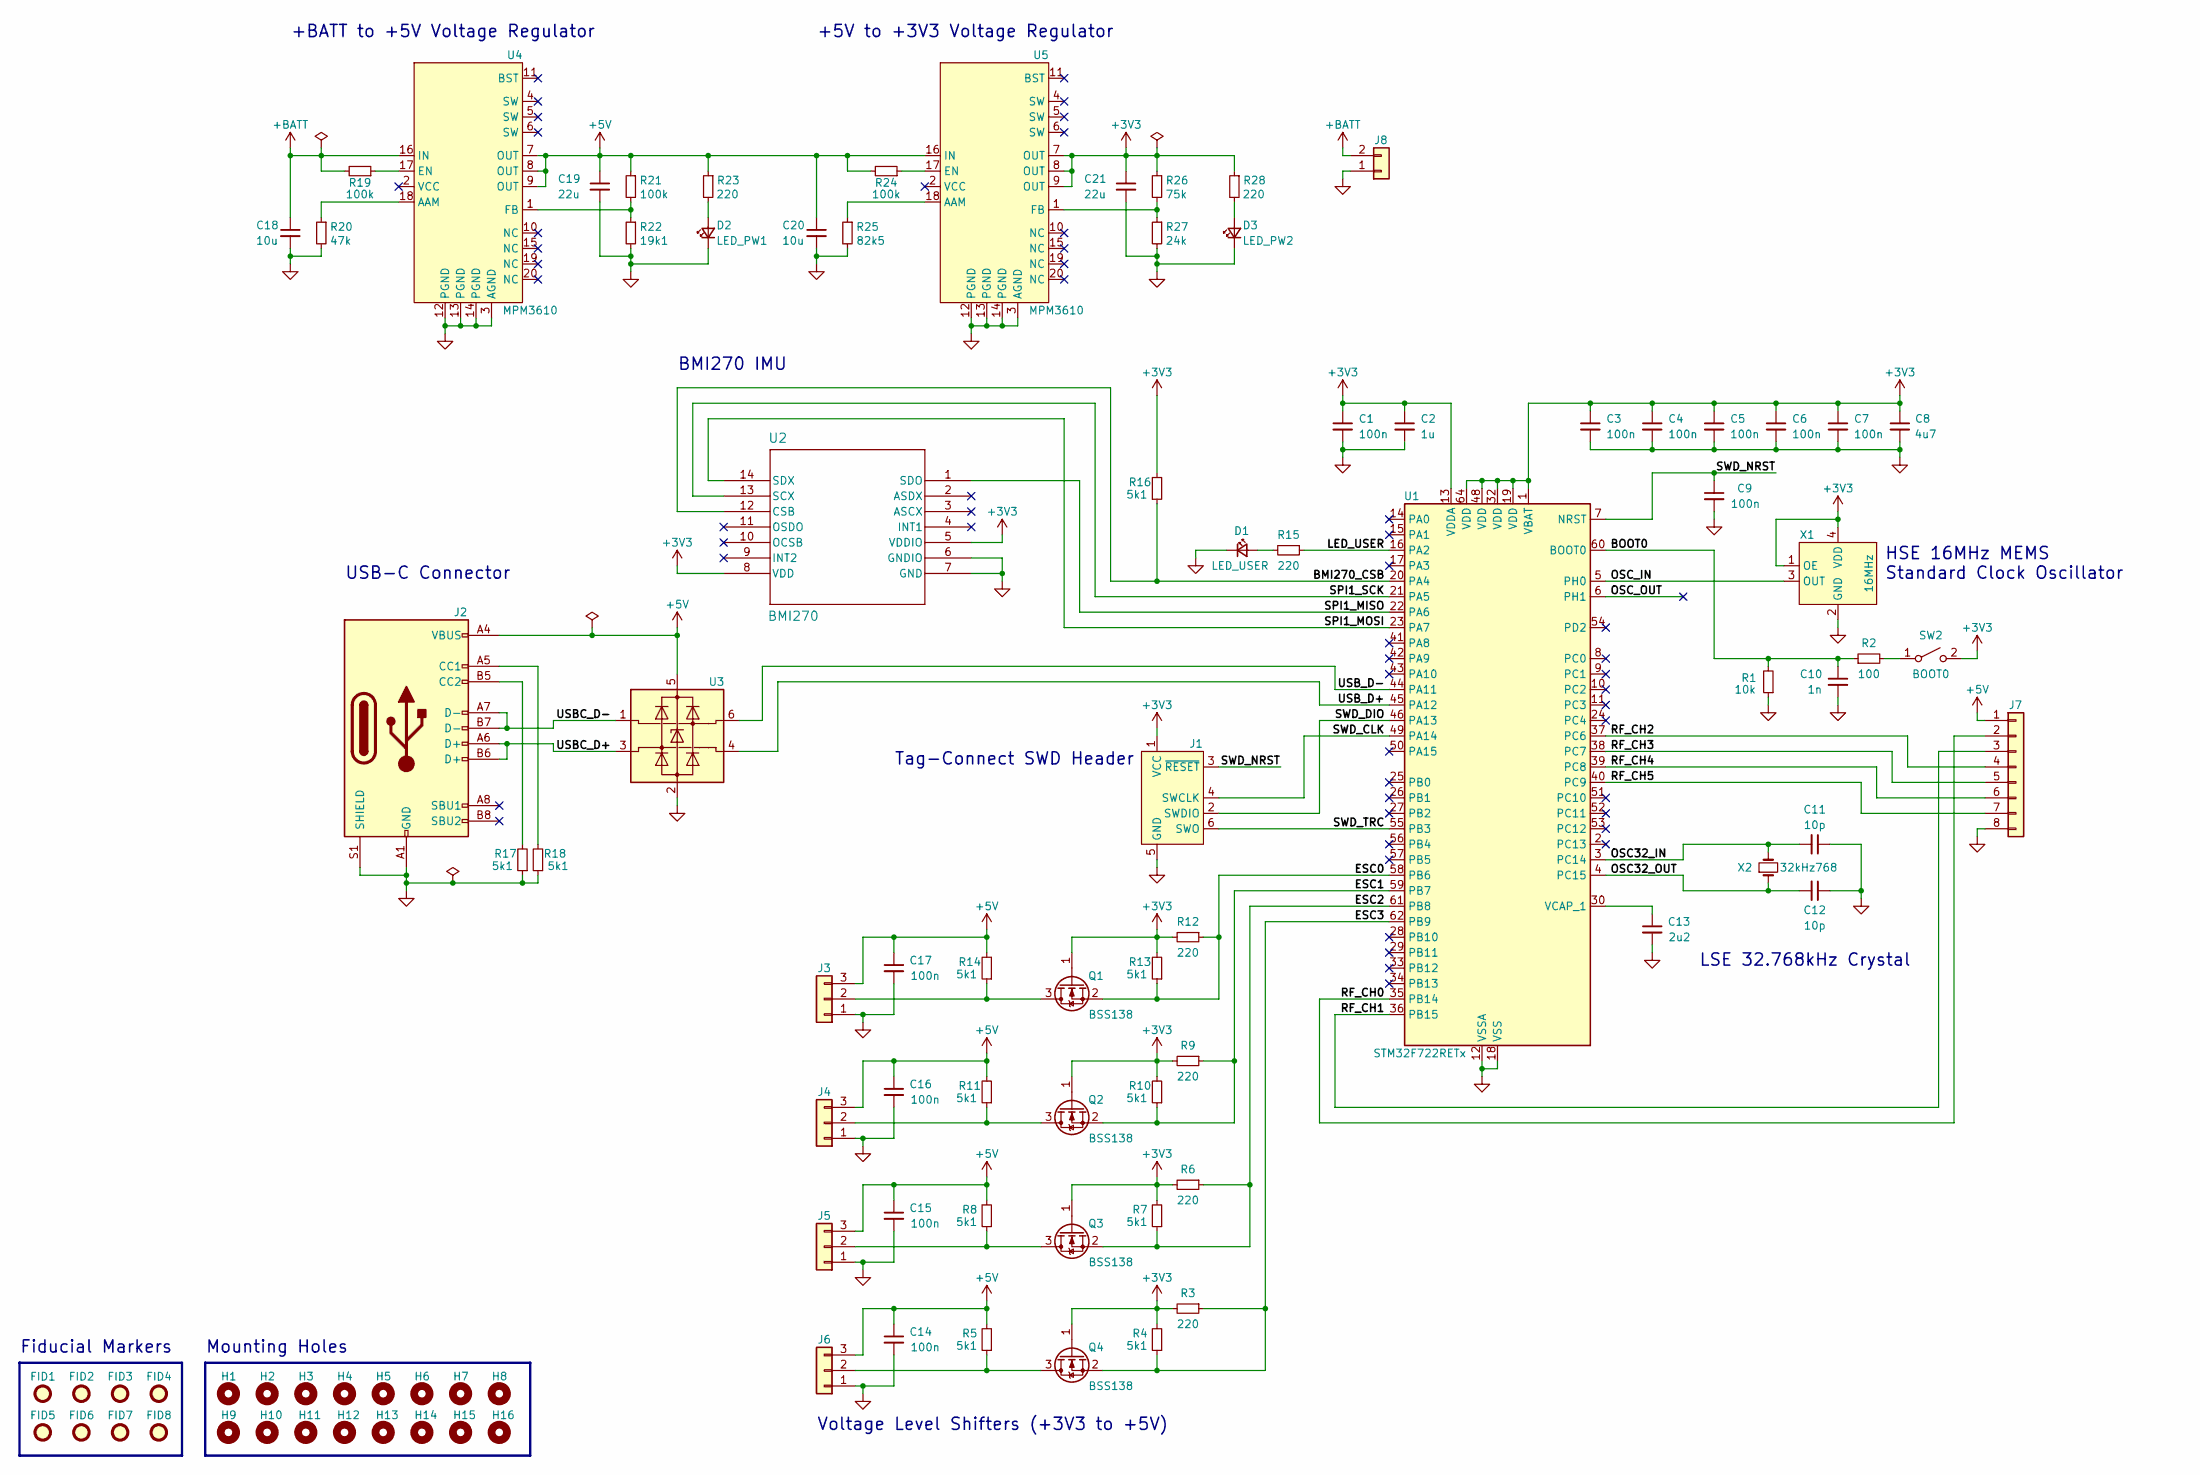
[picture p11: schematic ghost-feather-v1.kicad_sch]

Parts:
C1, C3, C4, C5, C6, C7, C9, C14, C15, C16, C17: 100n; C_0402_1005Metric
C2: 1u; C_0603_1608Metric
C8: 4u7; C_0603_1608Metric
C10: 1n; C_0402_1005Metric
C11, C12: 10p; C_0402_1005Metric
C13: 2u2; C_0603_1608Metric
C18, C20: 10u; C_0603_1608Metric
C19, C21: 22u; C_0603_1608Metric
D1: LED_USER; LED_0402_1005Metric; Manufacturer Part Number SML-P11VTT86R
D2: LED_PW1; LED_0402_1005Metric; Manufacturer Part Number SML-P11VTT86R
D3: LED_PW2; LED_0402_1005Metric; Manufacturer Part Number SML-P11VTT86R
FID1, FID2, FID3, FID4, FID5, FID6, FID7, FID8: Fiducial; Fiducial_1.5mm_Mask4.5mm
H1, H2, H3, H4, H5, H6, H7, H8, H9, H10, H11, H12, H13, H14, H15, H16: MountingHole; MountingHole_2.7mm_M2.5
J1: Conn_ARM_SWD_TagConnect_TC2030; Tag-Connect_TC2030-IDC-FP_2x03_P1.27mm_Vertical
J2: USB_C_Receptacle_USB2.0; USB_C_Receptacle_GCT_USB4105-xx-A_16P_TopMnt_Horizontal
J3, J4, J5, J6: Conn_01x03; Molex_PicoBlade_53048-0310_1x03_P1.25mm_Horizontal; Manufacturer Part Number 53048-0310
J7: Conn_01x08; Molex_PicoBlade_53048-0810_1x08_P1.25mm_Horizontal; Manufacturer Part Number 53048-0810
J8: Conn_01x02; AMASS_XT60PW-M_1x02_P7.20mm_Horizontal
Q1, Q2, Q3, Q4: BSS138; SOT-23
R1: 10k; R_0402_1005Metric
R2: 100; R_0402_1005Metric
R3, R6, R9, R12, R15, R23, R28: 220; R_0402_1005Metric
R4, R5, R7, R8, R10, R11, R13, R14, R16, R17, R18: 5k1; R_0402_1005Metric
R19, R21, R24: 100k; R_0402_1005Metric
R20: 47k; R_0402_1005Metric
R22: 19k1; R_0402_1005Metric
R25: 82k5; R_0402_1005Metric
R26: 75k; R_0402_1005Metric
R27: 24k; R_0402_1005Metric
SW2: BOOT0; SW_SPST_EVQPE1
U1: STM32F722RETx; LQFP-64_10x10mm_P0.5mm; Manufacturer Part Number STM32F722RET6
U2: BMI270; BMI270_BOS; Manufacturer Part Number BMI270
U3: USBLC6-2SC6_MOD; SOT-23-6; Manufacturer Part Number USBLC6-2SC6
U4, U5: MPM3610
X1: 16MHz; AMPMGFB_1.6mm1.2mm_16MHz; Manufacturer Part Number AMPMGFB-16.0000T
X2: 32kHz768; CC4V-T1A-32.768kHz; Manufacturer Part Number CC4V-T1A-32.768kHz-10pF-20PPM-TA-QC

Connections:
+3V3: C1.1, C2.1, C3.1, C4.1, C5.1, C6.1, C7.1, C8.1, C21.1, J1.1 (VCC), Q1.1 (G), Q2.1 (G), Q3.1 (G), Q4.1 (G), R3.2, R4.2, R6.2, R7.2, R9.2, R10.2, R12.2, R13.2, R16.2, R26.1, R28.1, SW2.2 (B), U1.1 (VBAT), U1.13 (VDDA), U1.19 (VDD), U1.32 (VDD), U1.48 (VDD), U1.64 (VDD), U2.5 (VDDIO), U2.8 (VDD), U5.7 (OUT), U5.8 (OUT), U5.9 (OUT), X1.1 (OE), X1.4 (VDD)
+5V: C14.1, C15.1, C16.1, C17.1, C19.1, C20.1, J2.A4 (VBUS), J2.A9 (VBUS), J2.B4 (VBUS), J2.B9 (VBUS), J3.3, J4.3, J5.3, J6.3, J7.1, R5.2, R8.2, R11.2, R14.2, R21.1, R23.1, R24.2, U3.5 (VBUS), U4.7 (OUT), U4.8 (OUT), U4.9 (OUT), U5.16 (IN)
+BATT: C18.1, J8.2, R19.2, U4.16 (IN)
/BMI270_CSB: R16.1, U1.20 (PA4), U2.12 (CSB)
/BOOT0: C10.1, R1.2, R2.1, U1.60 (BOOT0)
/ESC0: Q1.2 (S), R12.1, R13.1, U1.58 (PB6)
/ESC1: Q2.2 (S), R9.1, R10.1, U1.59 (PB7)
/ESC2: Q3.2 (S), R6.1, R7.1, U1.61 (PB8)
/ESC3: Q4.2 (S), R3.1, R4.1, U1.62 (PB9)
/LED_USER: R15.1, U1.16 (PA2)
/OSC32_IN: C11.2, U1.3 (PC14), X2.2
/OSC32_OUT: C12.2, U1.4 (PC15), X2.1
/OSC_IN: U1.5 (PH0), X1.3 (OUT)
/OSC_OUT: U1.6 (PH1)
/RF_CH0: J7.2, U1.35 (PB14)
/RF_CH1: J7.3, U1.36 (PB15)
/RF_CH2: J7.4, U1.37 (PC6)
/RF_CH3: J7.5, U1.38 (PC7)
/RF_CH4: J7.6, U1.39 (PC8)
/RF_CH5: J7.7, U1.40 (PC9)
/SPI1_MISO: U1.22 (PA6), U2.1 (SDO)
/SPI1_MOSI: U1.23 (PA7), U2.14 (SDX)
/SPI1_SCK: U1.21 (PA5), U2.13 (SCX)
/SWD_CLK: J1.4 (SWCLK), U1.49 (PA14)
/SWD_DIO: J1.2 (SWDIO), U1.46 (PA13)
/SWD_NRST: C9.1, J1.3 (~RESET), U1.7 (NRST)
/SWD_TRC: J1.6 (SWO), U1.55 (PB3)
/USBC_D+: J2.A6 (D+), J2.B6 (D+), U3.3 (I/O1)
/USBC_D-: J2.A7 (D-), J2.B7 (D-), U3.1 (I/O1)
/USB_D+: U1.45 (PA12), U3.4 (I/O2)
/USB_D-: U1.44 (PA11), U3.6 (I/O2)
GND: C1.2, C2.2, C3.2, C4.2, C5.2, C6.2, C7.2, C8.2, C9.2, C10.2, C11.1, C12.1, C13.2, C14.2, C15.2, C16.2, C17.2, C18.2, C19.2, C20.2, C21.2, D1.1 (K), D2.1 (K), D3.1 (K), J1.5 (GND), J2.A1 (GND), J2.A12 (GND), J2.B1 (GND), J2.B12 (GND), J2.S1 (SHIELD), J3.1, J4.1, J5.1, J6.1, J7.8, J8.1, R1.1, R17.1, R18.1, R20.2, R22.2, R25.2, R27.2, U1.12 (VSSA), U1.18 (VSS), U1.31 (VSS), U1.47 (VSS), U1.63 (VSS), U2.6 (GNDIO), U2.7 (GND), U3.2 (GND), U4.3 (AGND), U4.12 (PGND), U4.13 (PGND), U4.14 (PGND), U5.3 (AGND), U5.12 (PGND), U5.13 (PGND), U5.14 (PGND), X1.2 (GND)
unnamed: D1.2 (A), R15.2
unnamed: D2.2 (A), R23.2
unnamed: D3.2 (A), R28.2
unnamed: J2.A5 (CC1), R18.2
unnamed: J2.B5 (CC2), R17.2
unnamed: J3.2, Q1.3 (D), R14.1
unnamed: J4.2, Q2.3 (D), R11.1
unnamed: J5.2, Q3.3 (D), R8.1
unnamed: J6.2, Q4.3 (D), R5.1
unnamed: R2.2, SW2.1 (A)
unnamed: C13.1, U1.30 (VCAP_1)
unnamed: R20.1, U4.18 (AAM)
unnamed: R19.1, U4.17 (EN)
unnamed: R21.2, R22.1, U4.1 (FB)
unnamed: R25.1, U5.18 (AAM)
unnamed: R24.1, U5.17 (EN)
unnamed: R26.2, R27.1, U5.1 (FB)

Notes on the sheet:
HSE 16MHz MEMS Standard Clock Oscillator
Tag-Connect SWD Header
BMI270 IMU
LSE 32.768kHz Crystal
USB-C Connector
Voltage Level Shifters (+3V3 to +5V)
+5V to +3V3 Voltage Regulator
+BATT to +5V Voltage Regulator
Fiducial Markers
Mounting Holes

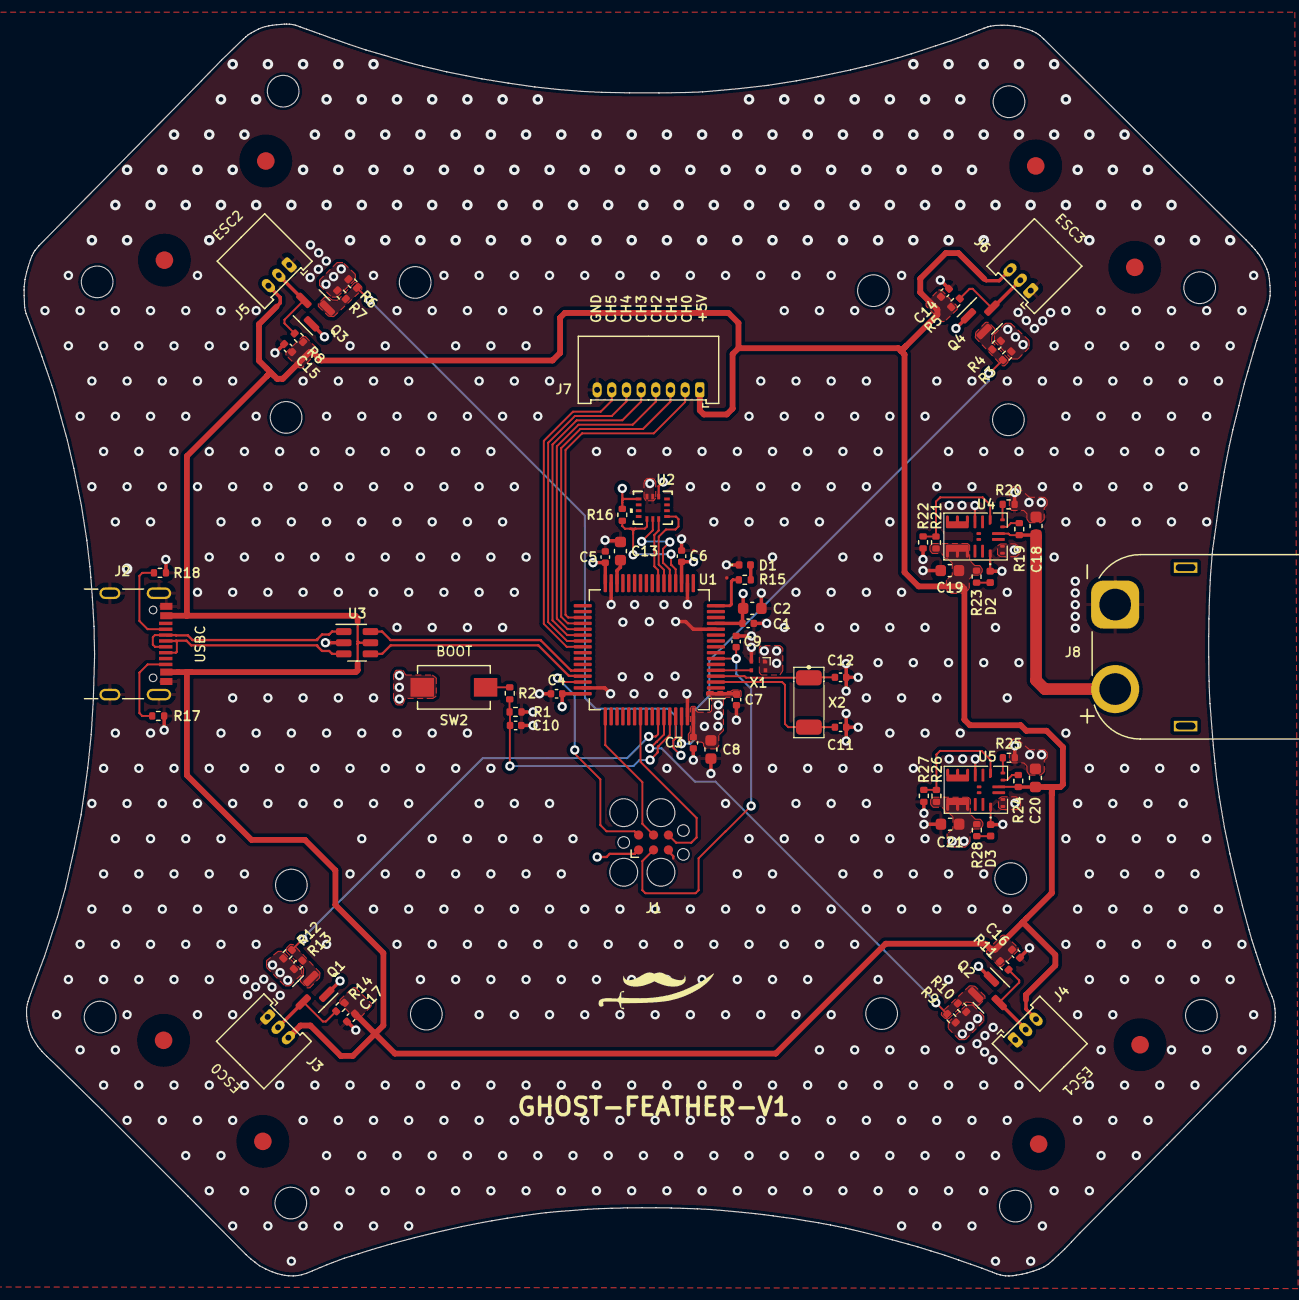
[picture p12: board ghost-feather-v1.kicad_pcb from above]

Board: 4 copper layers, 106.6 x 106.7 mm, 96 parts (0 on the bottom side), 48 nets.

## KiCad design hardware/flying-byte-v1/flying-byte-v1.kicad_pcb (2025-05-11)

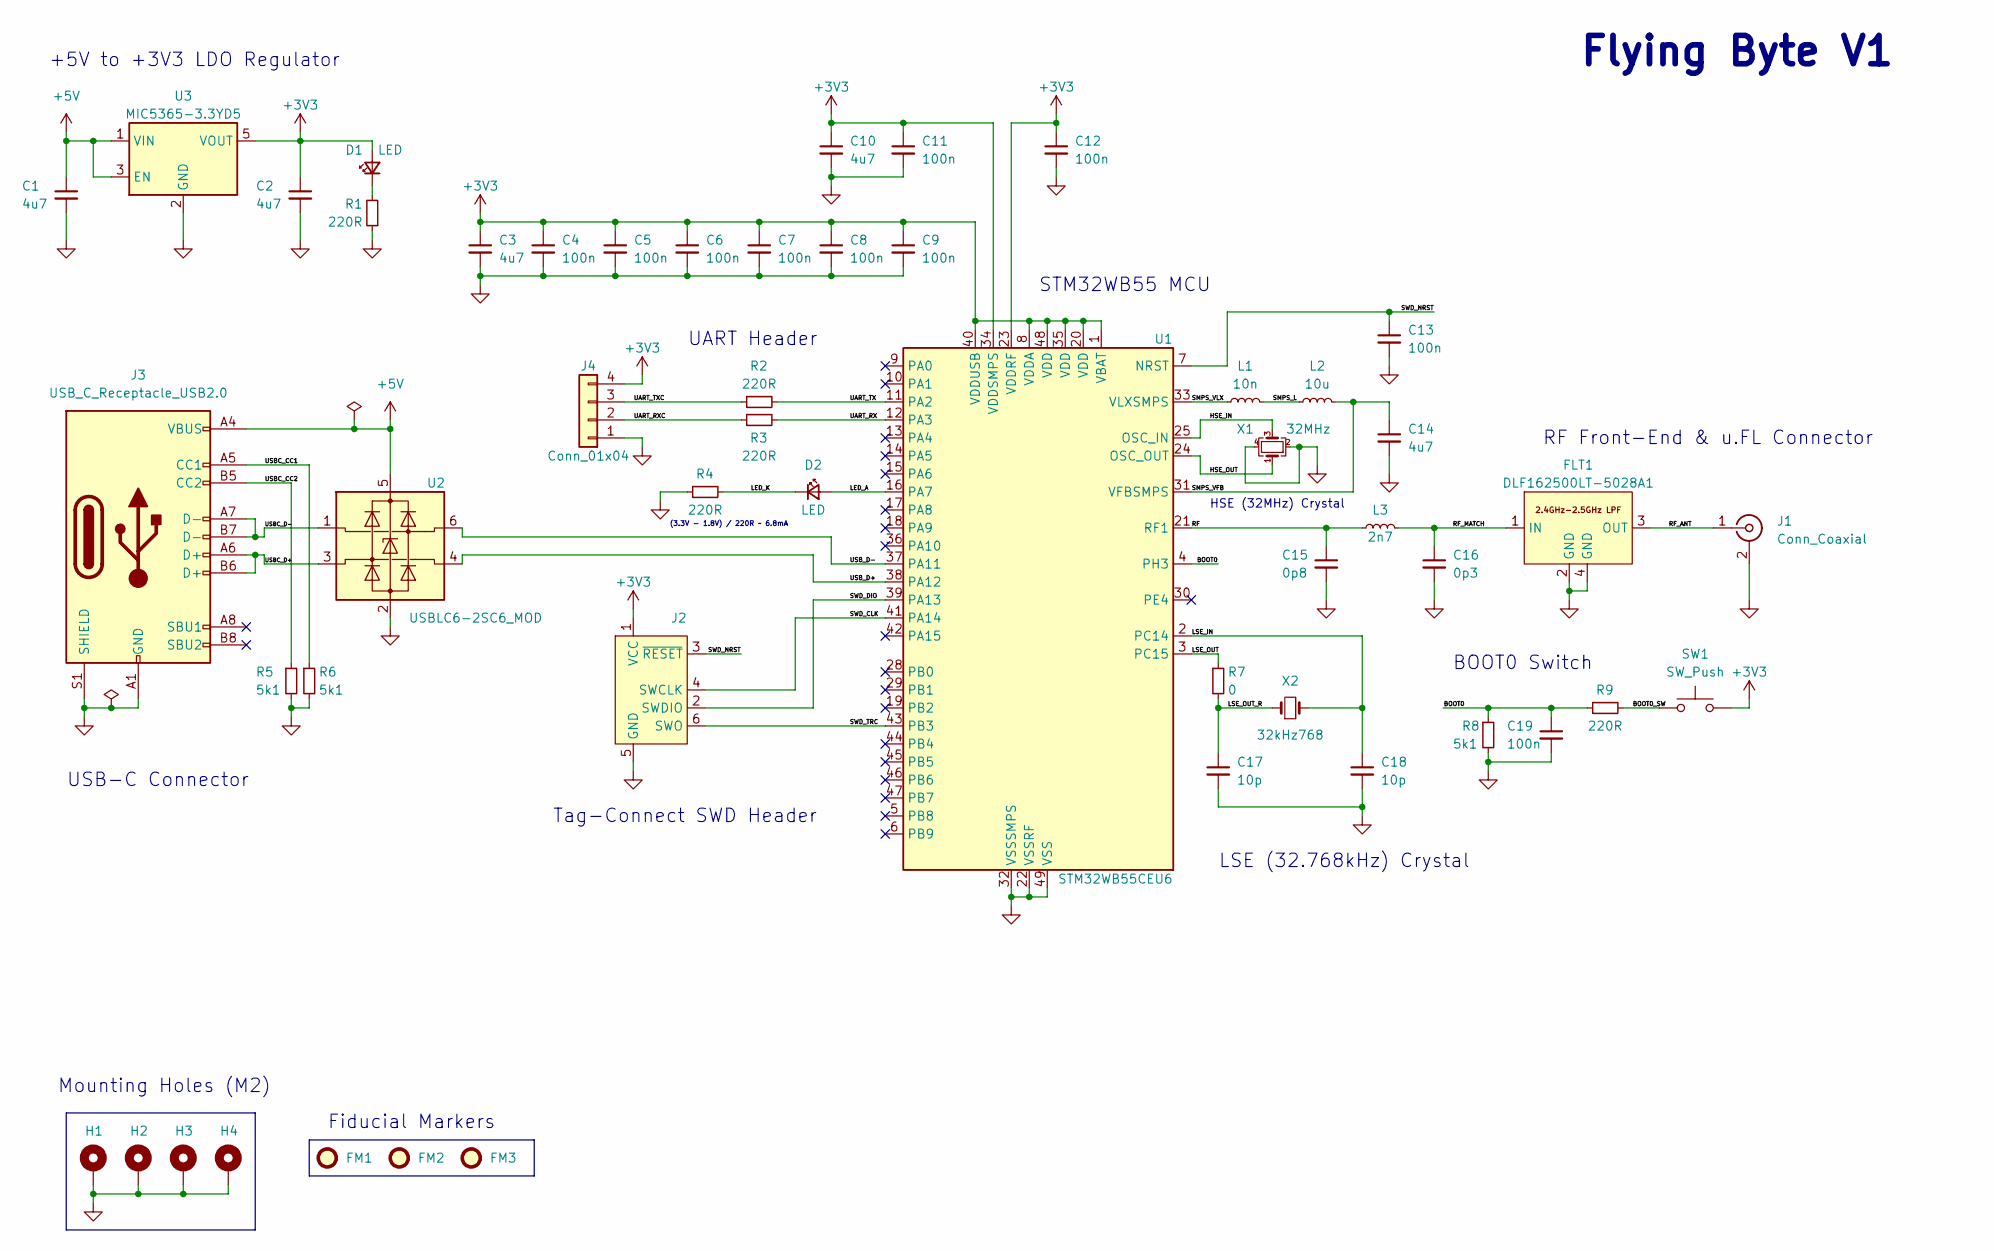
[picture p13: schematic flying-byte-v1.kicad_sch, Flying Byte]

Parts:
C1, C2, C3, C10, C14: 4u7; C_0603_1608Metric; Manufacturer Part Number GRT188R61E475KE13D
C4, C5, C6, C7, C8, C9, C11, C12, C13, C19: 100n; C_0402_1005Metric; Manufacturer Part Number 885012205092
C15: 0p8; C_0402_1005Metric; Manufacturer Part Number GRM1555C1HR80BA01D
C16: 0p3; C_0402_1005Metric; Manufacturer Part Number GRM1555C1HR30WA01D
C17, C18: 10p; C_0402_1005Metric; Manufacturer Part Number C0402C100J5RAC
D1: LED; LED_0402_1005Metric; Manufacturer Part Number FHR1105P-TR
D2: LED; LED_0402_1005Metric; Manufacturer Part Number FHY1105P-TR
FLT1: DLF162500LT-5028A1; Manufacturer Part Number DLF162500LT-5028A1
FM1, FM2, FM3: Fiducial; Fiducial_1mm_Mask2mm
H1, H2, H3, H4: MountingHole_Pad; MountingHole_2.2mm_M2_Pad
J1: Conn_Coaxial; U.FL_Hirose_U.FL-R-SMT-1_Vertical; Manufacturer Part Number U.FL-R-SMT(01)
J2: Conn_ARM_SWD_TagConnect_TC2030; Tag-Connect_TC2030-IDC-FP_2x03_P1.27mm_Vertical
J3: USB_C_Receptacle_USB2.0; USB_C_Receptacle_GCT_USB4105-xx-A_16P_TopMnt_Horizontal; Manufacturer Part Number USB4105-GF-A
J4: Conn_01x04; Molex_PicoBlade_53048-0410_1x04_P1.25mm_Horizontal; Manufacturer Part Number 53048-0410
L1: 10n; L_0402_1005Metric; Manufacturer Part Number LQG15WZ10NJ02D
L2: 10u; L_0805_2012Metric; Manufacturer Part Number LQM21FN100M80L
L3: 2n7; L_0402_1005Metric; Manufacturer Part Number LQG15HS2N7S02D
R1, R2, R3, R4, R9: 220R; R_0402_1005Metric; Manufacturer Part Number RNCF0402BKE220R
R5, R6, R8: 5k1; R_0402_1005Metric; Manufacturer Part Number RNCF0402BKE5K10
R7: 0; R_0402_1005Metric; Manufacturer Part Number MCS04020Z0000ZE000
SW1: SW_Push; SW_SPST_CK_RS282G05A3; Manufacturer Part Number RS282G05A3SMRT
U1: STM32WB55CEU6; QFN-48-1EP_7x7mm_P0.5mm_EP5.6x5.6mm; Manufacturer Part Number STM32WB55CEU6
U2: USBLC6-2SC6_MOD; SOT-23-6; Manufacturer Part Number USBLC6-2SC6
U3: MIC5365-3.3YD5; SOT-23-5; Manufacturer Part Number MIC5365-3.3YD5-TR
X1: 32MHz; Crystal_SMD_2016-4Pin_2.0x1.6mm; Manufacturer Part Number NX2016SA-32M-EXS00A-CS06465
X2: 32kHz768; Crystal_SMD_2012-2Pin_2.0x1.2mm; Manufacturer Part Number NX2012SA-32.768K-STD-MUB-1

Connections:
+3V3: C2.1, C3.1, C4.1, C5.1, C6.1, C7.1, C8.1, C9.1, C10.1, C11.1, C12.1, D1.2 (A), J2.1 (VCC), J4.4, SW1.2, U1.1 (VBAT), U1.8 (VDDA), U1.20 (VDD), U1.23 (VDDRF), U1.34 (VDDSMPS), U1.35 (VDD), U1.40 (VDDUSB), U1.48 (VDD), U3.5 (VOUT)
+5V: C1.1, J3.A4 (VBUS), J3.A9 (VBUS), J3.B4 (VBUS), J3.B9 (VBUS), U2.5 (VBUS), U3.1 (VIN), U3.3 (EN)
/BOOT0: C19.1, R8.1, R9.1, U1.4 (PH3)
/BOOT0_SW: R9.2, SW1.1
/HSE_IN: U1.25 (OSC_IN), X1.3
/HSE_OUT: U1.24 (OSC_OUT), X1.1
/LED_A: D2.2 (A), U1.16 (PA7)
/LED_K: D2.1 (K), R4.2
/LSE_IN: C18.1, U1.2 (PC14), X2.2
/LSE_OUT: R7.1, U1.3 (PC15)
/LSE_OUT_R: C17.1, R7.2, X2.1
/RF: C15.1, L3.1, U1.21 (RF1)
/RF_ANT: FLT1.3 (OUT), J1.1 (In)
/RF_MATCH: C16.1, FLT1.1 (IN), L3.2
/SMPS_L: L1.2, L2.1
/SMPS_VFB: C14.1, L2.2, U1.31 (VFBSMPS)
/SMPS_VLX: L1.1, U1.33 (VLXSMPS)
/SWD_CLK: J2.4 (SWCLK), U1.41 (PA14)
/SWD_DIO: J2.2 (SWDIO), U1.39 (PA13)
/SWD_NRST: C13.1, J2.3 (~RESET), U1.7 (NRST)
/SWD_TRC: J2.6 (SWO), U1.43 (PB3)
/UART_RX: R3.2, U1.12 (PA3)
/UART_RXC: J4.2, R3.1
/UART_TX: R2.2, U1.11 (PA2)
/UART_TXC: J4.3, R2.1
/USBC_CC1: J3.A5 (CC1), R6.1
/USBC_CC2: J3.B5 (CC2), R5.1
/USBC_D+: J3.A6 (D+), J3.B6 (D+), U2.3 (I/O1)
/USBC_D-: J3.A7 (D-), J3.B7 (D-), U2.1 (I/O1)
/USB_D+: U1.38 (PA12), U2.4 (I/O2)
/USB_D-: U1.37 (PA11), U2.6 (I/O2)
GND: C1.2, C2.2, C3.2, C4.2, C5.2, C6.2, C7.2, C8.2, C9.2, C10.2, C11.2, C12.2, C13.2, C14.2, C15.2, C16.2, C17.2, C18.2, C19.2, FLT1.2 (GND), FLT1.4 (GND), H1.1, H2.1, H3.1, H4.1, J1.2 (Ext), J2.5 (GND), J3.A1 (GND), J3.A12 (GND), J3.B1 (GND), J3.B12 (GND), J3.S1 (SHIELD), J4.1, R1.1, R4.1, R5.2, R6.2, R8.2, U1.22 (VSSRF), U1.32 (VSSSMPS), U1.49 (VSS), U2.2 (GND), U3.2 (GND), X1.2, X1.4
unnamed: D1.1 (K), R1.2

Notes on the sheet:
Flying Byte V1
RF Front-End & u.FL Connector
Tag-Connect SWD Header
BOOT0 Switch
STM32WB55 MCU
USB-C Connector
(3.3V - 1.8V) / 220R ~ 6.8mA
Fiducial Markers
+5V to +3V3 LDO Regulator
UART Header
Mounting Holes (M2)
HSE (32MHz) Crystal
LSE (32.768kHz) Crystal

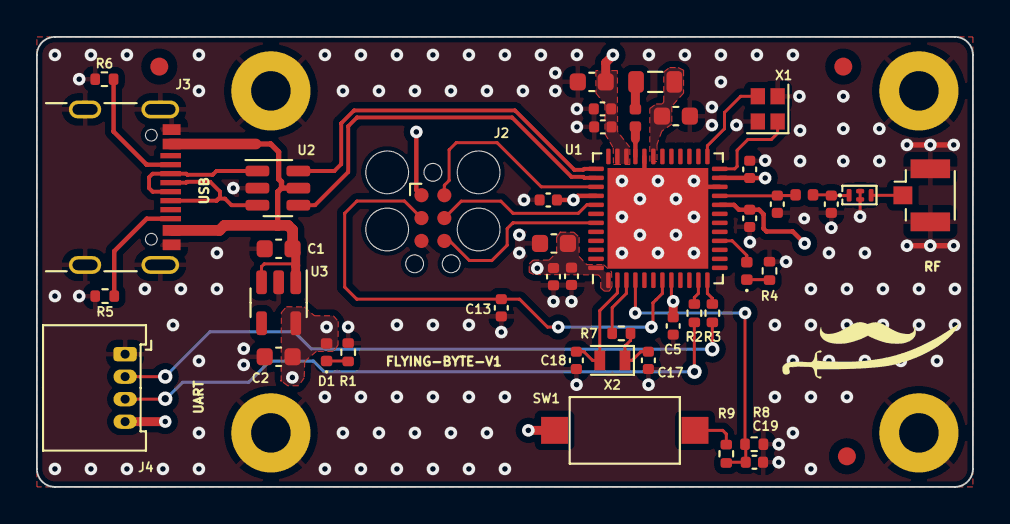
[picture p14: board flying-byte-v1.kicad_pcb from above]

Board: 4 copper layers, 52.0 x 25.0 mm, 51 parts (0 on the bottom side), 33 nets.

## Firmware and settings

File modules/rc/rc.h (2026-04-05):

#ifndef _RC_H
#define _RC_H

#include <stdint.h>
#include "tim.h"

#ifdef __cplusplus
extern "C" {
#endif  /* __cplusplus */

///
/// Used timers inside ghost feather system:
///
/// MOTOR0 -> TIM4_CH4  (PB9)   gp4_16
/// MOTOR1 -> TIM4_CH3  (PB8)   gp4_16
/// MOTOR2 -> TIM4_CH2  (PB7)   gp4_16
/// MOTOR3 -> TIM4_CH1  (PB6)   gp4_16
///
/// RFCH1  -> TIM12_CH1 (PB14)  gp2
/// RFCH2  -> TIM12_CH2 (PB15)  gp2
/// RFCH3  -> TIM8_CH1  (PC6)   adv4
/// RFCH4  -> TIM8_CH2  (PC7)   adv4
/// RFCH5  -> TIM8_CH3  (PC8)   adv4
/// RFCH6  -> TIM8_CH4  (PC9)   adv4
///
///  ----------------------------
/// |                    BAT |*+-|
/// |                    CH6 |s+-|  --> SWB
/// |                    CH5 |s+-|  --> SWA
/// |   FLYSKY FS-R6B    CH4 |s+-|  --> Yaw
/// |                    CH3 |s+-|  --> Throttle
/// |                    CH2 |s+-|  --> Pitch
/// |                    CH1 |s+-|  --> Roll
///  ----------------------------
///

///
/// \brief The 32-bit floating-ponit type.
///
typedef float float32_t;

///
/// \brief The RC channel identifiers.
///
typedef enum rc_ch
{
    RC_CH_BEGIN = 0,
    RC_CH_1     = 0,    /* Roll     */
    RC_CH_2,            /* Pitch    */
    RC_CH_3,            /* Throttle */
    RC_CH_4,            /* Yaw      */
    RC_CH_5,            /* SWA      */
    RC_CH_6,            /* SWB      */
    RC_CH_TOTAL,
} rc_ch_t;

///
/// \brief The RC channel normalization type.
///
typedef enum rc_norm
{
    RC_NORM_SYM = 0,
    RC_NORM_ASYM,
} rc_norm_t;

///
/// \brief The RC signal components.
///
struct rc_sig
{
    uint32_t raw;
    float32_t norm;
};

///
/// \brief The RC structure.
///
struct rc
{
    struct tim_dev *tim;
    struct ll_tim_ccr_data ccr_data;
    ll_tim_ccr_ch_t ccr_ch;
    struct rc_sig sig;
};

///
/// \brief Initializes the RC channel.
///
/// \param[in] handle The pointer to the RC channel.
/// \param[in] inst   The timer instance.
/// \param[in] ch     The timer capture/compare channel.
///
void rc_init(struct rc *const handle, const tim_inst_t inst, const ll_tim_ccr_ch_t ch);

///
/// \brief Denitializes the RC channel.
///
/// \param[in] handle The pointer to the RC channel.
///
void rc_deinit(struct rc *const handle);

///
/// \brief Gets RC channel.
///
/// \param[in] ch The RC channel.
///
/// \return struct rc* The RC channel pointer.
///
struct rc* rc_get(const rc_ch_t ch);

///
/// \brief Generates PWM pulse width from capture/compare register.
///
/// \param[in] handle The pointer to the RC channel.
///
void rc_sig_raw_gen(struct rc *const handle);

///
/// \brief Normalizes PWM pulse width for a given RC channel.
///
/// \param[in] handle The pointer to the RC channel.
/// \param[in] norm   The normalization type.
///
void rc_sig_norm(struct rc *const handle, const rc_norm_t norm);

#ifdef __cplusplus
}
#endif  /* __cplusplus */

#endif  /* _RC_H */

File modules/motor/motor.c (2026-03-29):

#include "motor.h"
#include "rc.h"
#include <string.h>

///***********************************************************************************************************
/// Private objects - definition.
///***********************************************************************************************************
///
/// \brief The motor devices array.
///
static struct motor motor_arr[MOTOR_INST_TOTAL];

///***********************************************************************************************************
/// Global functions - definition.
///***********************************************************************************************************
void motor_init(struct motor *const handle, const tim_inst_t inst, const ll_tim_ccr_ch_t ch)
{
    if (handle == NULL)
    {
        return;
    }

    /* TODO: Change tim_dev_arr_get() to tim_get() */
    struct tim_dev *tim_dev_arr = tim_dev_arr_get();

    handle->tim    = &tim_dev_arr[inst];
    handle->ccr_ch = ch;
}

void motor_deinit(struct motor *const handle)
{
    if (handle == NULL)
    {
        return;
    }

    memset(handle, 0, sizeof(struct motor));
}

struct motor* motor_get(const motor_inst_t inst)
{
    if ((inst < MOTOR_INST_BEGIN) || (inst >= MOTOR_INST_TOTAL))
    {
        return NULL;
    }

    return &motor_arr[inst];
}

void motor_update(const struct motor *const handle, const uint32_t pwm)
{
    if (handle == NULL)
    {
        return;
    }

    handle->tim->ccr_set(handle->tim->tim, handle->ccr_ch, pwm);
}

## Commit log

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2025-02-23 init: flying byte v1 hardware prototype
    [flying-byte-v1.kicad_pcb, flying-byte-v1.kicad_sch]
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2025-02-24 feature: Add the MCU power and decoupling
    [flying-byte-v1.kicad_sch]
2025-02-25 feature: Add the MCU SMPS
    [flying-byte-v1.kicad_sch]
2025-02-27 feature: Add the HSE and LSE crystals
    [flying-byte-v1.kicad_sch]
2025-02-28 feature: Add the RF section with LPF symbol and footprint
    [flying-byte-v1.kicad_sch]
2025-03-01 feature: Add the SWD programming interface
    [flying-byte-v1.kicad_sch]
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2025-03-02 feature: Add the BOOT0 interface
    [flying-byte-v1.kicad_sch]
2025-03-03 feature: Add the USBC and ESD protection
    [flying-byte-v1.kicad_sch]
2025-03-04 feature: Add the 3V3 LDO regulator, LEDs and UART connector.
    [flying-byte-v1.kicad_sch]
2025-03-05 feature: Assign footprints after ERC
    [flying-byte-v1.kicad_sch]
2025-03-05 feature: Add CSV file
    [flying-byte-v1.csv]
2025-03-06 doc: Add the page settings
    [flying-byte-v1.kicad_sch]
2025-03-07 feature: Add design rules
    [flying-byte-v1.kicad_pcb]
2025-03-08 feat: Add the net classes colors and initialize pcb with parts
    [flying-byte-v1.kicad_pcb]
2025-03-09 feat: Add the initial layout
    [flying-byte-v1.kicad_pcb, flying-byte-v1.kicad_sch]
2025-03-10 feat: Add outline, mounting holes and fiducial markers
    [flying-byte-v1.kicad_pcb, flying-byte-v1.kicad_sch]
2025-03-11 feat: PCB routing #1
    [flying-byte-v1.kicad_pcb]
2025-03-12 feat: PCB routing #2
    [flying-byte-v1.kicad_pcb, flying-byte-v1.kicad_sch]
2025-03-13 feat: PCB routing #3
    [flying-byte-v1.kicad_pcb]
2025-03-14 fix: Resolve DRC errors #1
    [flying-byte-v1.kicad_pcb]
2025-03-15 fix: Resolve DRC errors #2
    [flying-byte-v1.kicad_pcb]
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2025-03-16 init: Add ghost-feather-v1 kicad project
    [ghost-feather-v1.kicad_pcb, ghost-feather-v1.kicad_sch]
2025-03-17 feat: Add the MCU power and decoupling
    [ghost-feather-v1.kicad_sch]
2025-03-18 feat: Add the SWD programming interface
    [ghost-feather-v1.kicad_sch]
2025-03-20 fix: Change the stm32f722zet6 to stm32f722ret6. Apply the changes #1
    [ghost-feather-v1.kicad_sch]
2025-03-21 feat: Add HSE MEMS oscillator and LSE crystal
    [ghost-feather-v1.kicad_sch]
2025-03-22 Add BOOT0 interface, 3V3 buck converter, USBC, PWR LED and BMI270
    [ghost-feather-v1.kicad_sch]
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2025-03-23 feat: Assign PIN names for timers and LED
    [ghost-feather-v1.kicad_sch]
2025-03-24 feat: Add the notes for additional supply source and mosfet level shifter
    [ghost-feather-v1.kicad_sch]
2025-03-25 feat: Add the second switching regulator from VBATT to 5V
    [ghost-feather-v1.kicad_sch]
2025-03-26 feat: Add the MOSFET logic level shifters for every ESC
    [ghost-feather-v1.kicad_sch]
2025-03-27 feat: Add RF channel connector. Start adding the parts information
    [ghost-feather-v1.kicad_sch]
2025-03-28 feat: Assign footprints #1
    [ghost-feather-v1.kicad_sch]
2025-03-29 feat: Assign footprints #2
    [ghost-feather-v1.kicad_sch]
2025-03-30 feat: Assign footprints #3
    [ghost-feather-v1.kicad_sch]
2025-03-31 feat: Assign footprints #4
    [ghost-feather-v1.kicad_sch]
2025-04-01 feat: Assign footprints #5
    [ghost-feather-v1.kicad_sch]
2025-04-02 feat: Add PMIC related note
    [ghost-feather-v1.kicad_sch]
2025-04-03 feat: Add switching regulators related note
    [ghost-feather-v1.kicad_sch]
2025-04-04 feat: Add basic version of MPM3610 symbol
    [ghost-feather-v1.kicad_sch]
2025-04-04 feat: Add final version of MPM3610 symbol
    [ghost-feather-v1.kicad_sch]
2025-04-06 cleanup: Delete previous switching regulators (too big)
    [ghost-feather-v1.kicad_sch]
2025-04-07 feat: Add the MPM3610 switching regulators #1
    [ghost-feather-v1.kicad_sch]
2025-04-08 feat: Add the MPM3610 switching regulators #2
    [ghost-feather-v1.kicad_sch]
2025-04-11 feat: Assign basic version of MPM3610 footprint
    [ghost-feather-v1.kicad_sch]
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2025-04-14 feat: Add crystal and clock oscillator footprints #1
    [ghost-feather-v1.kicad_sch]
2025-04-15 feat: Add crystal and clock oscillator footprints #2
2025-04-15 feat: Add power flags to pass ERC
    [ghost-feather-v1.kicad_sch]
2025-04-16 feat: Start placing components on PCB
    [ghost-feather-v1.kicad_pcb]
2025-04-18 feat: Components placement on PCB #1
    [ghost-feather-v1.kicad_pcb]
2025-04-19 feat: Add f450 frame silkscreen
    [ghost-feather-v1.kicad_pcb]
2025-04-20 feat: Add design rules
    [ghost-feather-v1.kicad_pcb]
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2025-04-22 feat: Components placement on PCB #2
    [ghost-feather-v1.kicad_pcb, ghost-feather-v1.kicad_sch]
2025-04-23 feat: Components placement on PCB #3
    [ghost-feather-v1.kicad_pcb, ghost-feather-v1.kicad_sch]
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2025-05-06 feat: Remove errors and warnings
    [ghost-feather-v1.kicad_pcb]
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2025-05-14 chore: Add kicad directory and move all related files there
    [ghost-feather-v1.kicad_pcb, ghost-feather-v1.kicad_sch]
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2025-06-29 refactor: Change bmi270 all long names to shorter ones
    [bmi270.c]
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2025-07-04 fix: Correct typo in brief comment about bmi270 configuration structure
    [bmi270.c]
2025-07-07 fix: Add missing comma inside bmi270 device
    [bmi270.c]
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2025-07-21 fix: Solve the compilation errors for bmi270
    [bmi270.c]
2025-07-22 fix: Remove const qualifier from pointer target type in bmi270_wait_cycles function
    [bmi270.c]
2025-07-26 fix: Remove build warnings. Add extern C for gtest
    [bmi270.c]
2025-07-27 feat: Add mock for spi. Fix bmi270 get_dev unit test
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2025-07-31 fix: Change parameter indication for bmi270 accelerometer axes setters functions
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2025-08-13 fix: Change name of the gpio port enums
    [gpio.h]
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2025-08-26 fix: Change function name bmi270_get_pwr_mode_conf to bmi270_pwr_mode_get_conf
    [bmi270.c]
2025-08-27 fix: Change function name bmi270_get_dev to bmi270_dev_get
    [bmi270.c]
2025-08-28 feat: Improve resources sharing inside bmi270_acc_get_x test fixture class
    [acc_get_x.cc]
2025-08-28 feat: Improve resources sharing inside bmi270_acc_get_y test fixture class
    [acc_get_y.cc]
2025-08-28 feat: Improve resources sharing inside bmi270_acc_get_z test fixture class
    [acc_get_z.cc]
2025-08-28 feat: Improve resources sharing inside bmi270_acc_read test fixture class
    [acc_read.cc]
2025-08-29 feat: Improve resources sharing inside bmi270_acc_set_x test fixture class
    [acc_set_x.cc]
2025-08-29 feat: Improve resources sharing inside bmi270_acc_set_y test fixture class
    [acc_set_y.cc]
2025-08-29 feat: Improve resources sharing inside bmi270_acc_set_z test fixture class
    [acc_set_z.cc]
2025-08-29 feat: Improve resources sharing inside bmi270_acc_slf_tst test fixture class
    [acc_slf_tst.cc]
2025-08-29 feat: Improve resources sharing inside bmi270_deinit test fixture class
    [deinit.cc]
2025-08-30 fix: Rename bmi270 get_dev unit test to dev_get
    [dev_get.cc]
2025-09-01 fix: Change temperature data type from unsigned to signed
    [bmi270.c]
2025-09-03 fix: Adjust tx_idx inside SetUp and TearDown for acc_read, gyr_read, temp_read and time_read unit tests
    [acc_read.cc]
2025-09-04 fix: Remove unused part of the code. The status is changed in spi_ctrl_begin and spi_ctrl_end functions
    [bmi270.c]
2025-09-07 fix: Remove unnecessary else statements from bmi270_pwr_mode_set function
    [bmi270.c]
2025-09-08 doc: Part of bmi270_init violates SOLID priciples. Add TODO comment to fix it
    [bmi270.c]
2025-09-09 fix: Apply changes related to SOLID principles to bmi270_init function. Change spi_ctrl_dev_get function to simpler one
    [bmi270.c]
2025-09-10 fix: Add check if spi_ctrl is null inside bmi270 dev insie bmi270_soft_rst function. Update unit tests
    [bmi270.c]
2025-09-11 fix: Add check if spi_ctrl is null inside bmi270_acc_read function. Update unit tests
    [acc_read.cc, bmi270.c]
2025-09-13 fix: Add missing struct keyword
    [acc_set_y.cc, acc_set_z.cc, acc_slf_tst.cc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]
2025-09-14 fix: Add spi_ctrl wherever needed in bmi270 source file
    [bmi270.c]
2025-09-16 fix: Add acc_slf_tst_reg to preserve register value
    [bmi270.c]
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2025-09-19 fix: Align the spaces inside acc_slf_tst unit test
    [acc_slf_tst.cc]
2025-09-20 fix: Change register address inside bmi270 cmd_soft_rst function from PWR_CONF to CMD
    [bmi270.c]
2025-09-24 fix: Update the LED pin inside app
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2025-10-13 fix: Add missing spi set baud rate function inside initialization
2025-10-14 fix: Change spi baud rate to one without bit shiftig
2025-10-16 bug: SPI SSM set function bug found and marked
2025-10-17 fix: Set pullup resistor for gpio4 used as nss for spi1
    [bootloader.c]
2025-10-19 fix: Delete unused function. Fix errors related to bmi270 read/write functions
    [bmi270.c]
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2025-10-22 fix: Change bmi270 spi read/write functions. Now they operates on bytes not halfwords
    [bmi270.c]
2025-10-23 fix: Change the validation of the bmi270 config file function
    [bmi270.c]
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2025-10-25 fix: Refactor the bmi270 init function #1
    [bmi270.c]
2025-10-26 fix: Refactor the bmi270 init function #2
    [bmi270.c]
2025-10-27 fix: Refactor the bmi270 pwr mode set function #1
    [bmi270.c]
2025-10-28 fix: Refactor the bmi270 init function #3
    [bmi270.c]
2025-10-28 fix: Refactor the bmi270 accelerometer related functions #1
    [bmi270.c]
2025-10-29 fix: Refactor rest of the bmi270 functions
    [bmi270.c]
2025-10-30 fix: Make stack bigger it resolves problem with bmi270 config file validation
    [bmi270.c]
2025-10-31 fix: The buffer indexes while reading bmi270 accelerometer and gyroscope data
    [bmi270.c]
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2025-12-18 fix: Replace breif to brief inside comments
    [bmi270.c]
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2025-12-24 fix: Remove ghost_feather_common header file from apploader
    [apploader.c]
2025-12-26 fix: Remove TODOs from bootloader.c
    [bootloader.c]
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2025-12-28 fix: Delete unused ghost feather common module
    [ghost_feather_common.h]
2025-12-29 feat: fix: wip: Add ghost feather launch and land procedure functions. Fix tim_ctrl bugs. Start working on ghf module
    [app.c, apploader.c, ghf.c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]
2025-12-31 fix: Add temporary ghost_feather_common files. They will be removed in a future
    [ghost_feather_common.h]
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2026-01-06 fix: Set BMI270 CSB pin to high (default output state is LOW)
    [bootloader.c]
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2026-01-09 fix: Change motor_inst_t enum to motor_t
    [app.c, motor.c]
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2026-01-18 fix: Delete controller and core dirs. Remove tim_ctrl related functions
    [ghf.c, ll_tim_advx.c, ll_tim_gpx.c]
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2026-03-16 fix: Add comma where its missing
    [app.c]
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2026-04-02 fix: Change the global ghf_setup and ghf_calib functions to private functions inside ghf module. Resolve NULL pointer bug
    [app.c, ghf.c]
2026-04-06 fix: Update argument name inside safe mode function
    [app.c]
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2026-04-12 fix: Adjust pitch in the motor mixer
    [app.c]
2026-04-21 feat: hardware: Add ghost-feather-v2 kicad project. Finish power supply decoupling capacitors scheme for stm32f722xx
    [ghost-feather-v2.kicad_pcb, ghost-feather-v2.kicad_sch]
2026-04-22 feat: hardware: Add ghost-feather-v2 TAG Connector and user LED
    [ghost-feather-v2.kicad_sch]
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2026-04-26 feat: hardware: wip: Add USB, SENSORS and MCU sectors on schematic
    [ghost-feather-v2.kicad_sch]
2026-04-27 feat: hardware: Finish SENSORS and MCU sectors on schematic
    [ghost-feather-v2.kicad_sch]
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2026-04-29 feat: hardware: Add crystals for nRF52810. Add voltage level shifters for ESCs
    [ghost-feather-v2.kicad_sch]
2026-04-30 fix: hadware: Remove RF_CH0-RF_CH5 due to the fact of using different receiver
    [ghost-feather-v2.kicad_sch]
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2026-05-02 feat: hadware: Finish USBC and add TVS diode protection
    [ghost-feather-v2.kicad_sch]
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2026-05-12 feat: software: wip: Add I2C low level driver #6. Adds software reset function
    [ll_i2c.c, ll_i2c.h]
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2026-05-17 feat: software: wip: Add I2C low level driver #16. Software reset function refactor
    [ll_i2c.c, ll_i2c.h]
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2026-05-19 fix: software: wip: Add I2C low level driver #21. Fix the bugs
    [ll_i2c.c, ll_i2c.h]
2026-05-20 fix: software: wip: Add I2C low level driver #22. Remove ll_i2c_regs_por
    [ll_i2c.c]
2026-05-21 fix: software: wip: Add I2C low level driver #23. Removes master/slave init/deinit functions. Adds peripheral enable/disable functions
    [ll_i2c.c, ll_i2c.h]
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2026-05-23 feat: software: wip: Add I2C low level driver #28. Add analog noise filter enable/disablefunctions
    [ll_i2c.c, ll_i2c.h]
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2026-05-24 fix: software: wip: Add I2C low level driver #31. Apply naming convention for all functions
    [ll_i2c.c, ll_i2c.h]
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2026-05-28 fix: software: wip: Add I2C low level driver #42. Use uppercase I2C in doxygen comments
    [ll_i2c.h]
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
